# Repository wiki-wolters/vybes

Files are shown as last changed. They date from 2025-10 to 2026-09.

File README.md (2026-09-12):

# Vybes, a home DSP project

Vybes is a DSP, designed for flexibility and multiple presets covering parametric EQ, FIR
filter room correction, speaker delays, and subwoofer crossover, all controlled via a web
interface over WIFI.

## Internals

At the core of the device is a Teensy 4.1 with a 600MHz processor. The Teensy is
responsible for all the digital audio manipulation: input mixing, parametric EQ, FIR
filtering, speaker delays, subwoofer crossover, and tone/pink-noise generation.

An ESP32 development board (classic DevKitC/WROOM-32 or ESP32-S3 DevKitC-1 - both are supported build targets) is responsible for connecting to WIFI, serving the
web UI and API, and managing Teensy state. Preset configuration is stored on the
ESP32's flash (LittleFS, as MessagePack), alongside the built web UI assets.

Audio inputs (into the Teensy):
* SPDIF Toslink optical
* Bluetooth receiver via I2S
* USB audio (the Teensy enumerates as a USB sound card; built with `USB_MIDI_AUDIO_SERIAL`)
* Analogue stereo line-in via a second I2S input (an ADC board)

Audio outputs:
* Analog L & R via an I2S DAC board (PCM5102A)
* Analog subwoofer via a second PCM5102A I2S DAC board
* SPDIF pass-through out

Other hardware handled by the ESP32:
* A 1602 backlit LCD (via an I2C PCF8574 backpack) shows the current preset name. The
  backlight turns on when the preset changes and turns off after a few seconds.
* A front button: a short press wakes the LCD backlight, further presses cycle through
  presets (the selection is applied one second after the last press). Holding the button
  for ~3 seconds triggers Bluetooth pairing (the ESP drives the Bluetooth module's
  pairing line high while held).
* An IR receiver, so a spare remote control can drive volume up/down, mute, and
  next/previous preset.

WIFI credentials are provisioned by WiFiManager: if the ESP32 can't connect, it
automatically opens a "Vybes-Config" access point that a phone can join to enter
credentials. Once on the network it registers itself via mDNS so the device is
reachable at http://vybes.local.

The server also listens on **https://vybes.local** when TLS certificates are
present on the device (LittleFS `/certs/server.crt` + `/certs/server.key`;
without them it serves plain HTTP only). Generate them with `ESP/make-certs.sh`
(uses [mkcert](https://github.com/FiloSottile/mkcert)) and flash with
`pio run -d ESP -t uploadfs`. Trust the mkcert root CA on a phone or laptop
(instructions in the script header) and the browser treats the device as a
secure origin — which is what allows microphone access for the Analyzer's mic
overlay, notably on iOS where there is no insecure-origin override.

The config portal also has a "Standalone mode (no router)" button for use away from
any WIFI network (e.g. in the car): it brings up a plain "Vybes" access point
(password `vybes-dsp`) serving the full web UI at http://192.168.4.1. The AP
deliberately has no captive portal or internet, so phones keep streaming (Spotify,
Bluetooth audio) over cellular while connected to it — confirm the "no internet,
stay connected?" prompt once. Standalone mode lasts until the next power cycle.

FIR filter files live on an SD card in the Teensy 4.1's built-in slot; the ESP asks the
Teensy for the list of available files and tells it which file to load per channel.

## Presets

Up to 8 presets are stored (see `ESP/esp-web-server/config.h`). Presets follow the
8-output channel architecture (see `docs/CHANNEL_ARCHITECTURE.md`): a routing matrix
into eight identical output channels rather than a fixed left/right/sub set. Each
preset contains:

* Name (max 15 characters) and a speaker-setup template reference
* Input EQ (the shared "preference curve"): up to 15 points (frequency, gain, Q)
  plus an enabled flag, and a *dynamic EQ* that follows the volume — a reference
  anchor, an optional louder one sharing the same bands, and an automatic
  ISO 226-derived loudness compensation below the reference. See
  [docs/DYNAMIC_EQ.md](docs/DYNAMIC_EQ.md).
* Crossover points: named frequency + enabled pairs that outputs reference for
  their high- and low-pass filters (a shared point keeps linked outputs in sync)
* Eight outputs, each with: label, enable, source mix (per-bus gains), high-pass
  and low-pass crossover assignment, gain, delay in microseconds, FIR filter
  filename, a per-output PEQ (up to 10 points) + enabled flag, mute, and invert
* Preset-level enable flags for delays and FIR filtering
* Master volume (0-100): each preset remembers the level it was last played at,
  and activating a preset restores it

Global (non-preset) state includes dim (volume-reduction) state and percentage,
input gains (bluetooth, spdif, usb, analog, plus the tone/noise and SD-playback
levels), and the tone/pink-noise generator settings.

## Web UI

A Vue 3 + Vite single-page app (in `/WebUI`), served by the ESP32. Three views, plus
a persistent generator dock (tone / pink noise with a start/stop button — frequency
for the tone, and a level per source) available from every view:

### Home
* Presets: a button for each, and a plus icon to add new. Tapping the active preset's
  edit icon navigates to the preset editor. Switching is locked while recording.
* Master volume slider (the active preset's stored level)
* Speaker on/off toggles
* Dim: volume-reduction percentage slider and on/off toggle
* Input source: a stereo peak meter on the summed input bus (all sources plus SD
  playback — the point that clips when sources stack up, and exactly what the
  recorder captures), and gain sliders in dB for Bluetooth, TV (SPDIF), USB, and
  Analog
* Dynamics: the multiband compressor controls
* Recorder: record the input mix or playback to the Teensy's SD card, and play
  recordings back
* Configuration: backup and restore buttons (download/upload the full device config;
  restore is locked while recording)

### Analyzer
Real-time 31-band (1/3-octave) spectrum overlay:
* Source trace: the Teensy taps the L+R input mix (pre-DSP) with an FFT and
  streams band levels while the page is open
* Microphone trace: captured in the browser via Web Audio, aggregated into the
  same bands. Mic calibration is applied from a built-in profile (a generic
  smartphone high-pass model, or an iPhone 17 Pro curve digitised from Faber
  Acoustical's anechoic measurement) or an imported REW-style cal file
  (.txt/.cal/.frd/.csv); the choice persists in the browser.
* The capture is requested raw (no echo cancellation, noise suppression, or auto
  gain) and what the browser actually granted is read back and displayed —
  including an explicit "unknown" when the browser won't say
* The mic trace is auto level-aligned to the source (median offset over the
  analysis band), and a delta chart shows mic − source: where the room and system
  boost or lose energy. Play pink noise for the most meaningful delta.
* Exponential averaging (0.5–8 s) smooths both traces and absorbs the timing
  difference between the device tap and the mic path
* Auto-EQ ("EQ Correction"): capture the delta at one or more mic positions
  (power-domain averaged), pick a target curve (flat, tilt, Harman, B&K, or a
  custom REW import), set correction strength and boost/cut limits, preview the
  fitted bands, and apply — either to the shared input EQ, or to a single output
  (the device solos that output while measuring, and the fit is confined to its
  crossover passband)
* Note: browsers only expose the microphone on secure origins (HTTPS or
  localhost), so the mic overlay doesn't work on a phone browsing the device
  over plain HTTP. On a laptop, Chrome's
  `#unsafely-treat-insecure-origin-as-secure` flag is the workaround.

### Preset editor
Rename, copy, and delete buttons and a speaker-setup template badge, then two tabs:

**Tuning** — the day-to-day controls:
* EQ: the shared input EQ — an interactive parametric chart with draggable points
  and a calculated frequency-response curve, plus REW import (paste REW's "Export
  filter settings as text" output or choose the exported .txt; peaking (PK)
  filters are imported, up to the band limit). Above the chart are the dynamic-EQ
  controls: the reference volume the curve is tuned at, an optional loud anchor
  (add / move to the current volume / remove) with a Reference | Loud switch for
  which set of gains the chart edits, and the loudness-compensation toggle. A
  dashed "Now at NN%" curve shows what is actually playing when it differs from
  the curve being edited. See [docs/DYNAMIC_EQ.md](docs/DYNAMIC_EQ.md)
* FIR filters: a file dropdown per enabled output listing the filter files on the
  device's SD card (a configured-but-missing file stays selectable rather than
  being silently blanked, and there's a free-text fallback when the list is
  unavailable), with a taps-used counter against the device's FIR pool
* Crossovers: the preset's named crossover points (frequency + enable), each
  showing which outputs' high-/low-pass filters reference it
* Speaker delays: an input per enabled output, in microseconds, plus an
  "Auto-align with phone mic" wizard on the active preset — it plays chirps
  through each output and measures arrival times with the phone's microphone
* Output levels: a gain slider per enabled output
* Master volume: the level this preset plays at, restored whenever it is activated

**Channels** — the full 8-output matrix, one strip per output: editable label,
enable toggle, source mix, high-pass and low-pass crossover assignment (with a
protected floor when one is set), gain, delay, FIR file, a per-output PEQ (up to
10 bands, same editor and REW import as the input EQ), and mute/invert toggles.
A FIR pool bar tracks tap usage and load errors across outputs.

## API

HTTP on port 80 and HTTPS on 443 (same routes; HTTPS only when certificates are installed). Parameters are query strings unless a JSON body is noted.

### System
* **GET /status** — current state: speaker gains, input gains, mute, tone and noise
  generator settings, master volume, and the active preset name
* **PUT /volume?value={0-100}[&preset_name={name}]** — master volume. It is stored
  per preset: without `preset_name` the write lands on the active preset (the live
  master volume); naming a preset sets the level it will play at without changing
  what is playing now
* **PUT /mute?state={on|off}**
* **PUT /mute/percent?percent={0-100}** — how much mute reduces the volume
* **GET /backup** — download the device configuration (MessagePack)
* **POST /restore** — upload a previously downloaded configuration (multipart file)

### Gains
* **PUT /gains/speaker?speaker={left|right|sub}&value={0-100}** — gain in percent
* **PUT /gains/input** — JSON body, any of: `{ "spdif": n, "bluetooth": n, "usb": n, "tone": n, "analog": n }`
* **GET /preset/gains?preset_name={name}**
* **PUT /preset/gains?preset_name={name}** — JSON body of per-speaker gains

### Signal generator
* **PUT /generate/tone?frequency={20-20000}&volume={0-100}**
* **PUT /generate/tone/stop**
* **PUT /noise?level={0-100}** — 0 turns noise off

### Preset management
* **GET /presets** — all presets with names and which is current
* **GET /preset?name={name}** — full preset configuration
* **POST /preset?action=create&name={name}**
* **POST /preset?action=copy&source={name}&destination={name}**
* **PUT /preset?action=rename&old_name={name}&new_name={name}**
* **DELETE /preset?name={name}**
* **PUT /preset/active?name={name}** — switch the active preset

### Preset configuration
* **PUT /preset/delay?preset_name={name}&speaker={left|right|sub}&value={0-20000}** — delay in µs (20 ms max)
* **PUT /preset/delay/enabled?preset_name={name}&state={on|off}**
* **PUT /preset/eq?preset_name={name}** — JSON body: array of `{ "freq": 20-20000, "gain": -15-15, "q": 0.1-10 }`
* **PUT /preset/eq/point?preset_name={name}** — JSON body: single point `{ "id": 0-14, "freq": n, "gain": n, "q": n }`
* **PUT /preset/eq/enabled?preset_name={name}&enabled={on|off}**
* **PUT /preset/crossover?preset_name={name}&frequency={20-20000}**
* **PUT /preset/crossover/enabled?preset_name={name}&enabled={on|off}**

### FIR filters
* **GET /fir/files** — list of filter files on the Teensy's SD card
* **PUT /preset/fir?preset_name={name}&speaker={left|right|sub}&file={filename}**
* **PUT /preset/fir/enabled?preset_name={name}&state={on|off}**

### Live updates (WebSocket)
* **ws://vybes.local/live-updates** (or `wss://` when the page is served over HTTPS)
  * State changes are broadcast to all connected clients as JSON with a `messageType`
    field: `volumeChanged` (with the `presetName` the level belongs to),
    `muteChanged`, `mutePercentChanged`, `activePresetChanged` (which carries the
    newly active preset's `volume`),
    `delayChanged`, `delayEnabledChanged`, `eqPointsChanged`, `eqEnabledChanged`,
    `crossoverChanged`, `crossoverEnabledChanged`, `firChanged`, `firEnabledChanged`,
    plus payload fields (usually `presetName` and the new value).
  * Tone and noise updates are broadcast as `{ "toneFrequency": n, "toneVolume": n }`
    and `{ "noiseVolume": n }` (no `messageType` field).
  * RTA: clients send the text message `rta:keepalive` every 2 s while they want
    spectrum data; the server relays the interest to the Teensy and broadcasts
    frames as `{ "type": "rta", "d": "<62 hex chars>" }` — two hex digits per
    band (31 bands, 20 Hz–20 kHz), value = (dB + 100) × 2. Streaming stops a few
    seconds after the keepalives do.

## Directories
* `/ESP`: ESP32 web server firmware (API, WebSocket, HTTPS, LCD, button, IR remote, WIFI)
* `/Teensy`: Teensy DSP firmware (`fir_filters/`)
* `/WebUI`: Vue 3 web UI
* `/mock-server`: Express + SQLite mock of the device API, for developing the web UI
  without hardware (includes the WebSocket endpoint)
* `/docs`: wiring and protocol documentation
* `/3d`: 3D-printable case models

## Building and flashing

Both firmwares build with [PlatformIO](https://platformio.org) — no Arduino IDE needed.
PlatformIO downloads the right toolchains, frameworks, and libraries automatically on
the first build.

### One-time setup

Install the PlatformIO CLI, e.g. one of:

```sh
brew install platformio    # macOS (Homebrew)
pipx install platformio    # anywhere with Python
pip install platformio     # what CI uses
```

(Alternatively, install the "PlatformIO IDE" extension in VS Code, which bundles the
`pio` CLI and adds build/upload buttons.)

The web UI needs Node.js. Install its dependencies once:

```sh
cd WebUI && npm install
```

### Teensy (DSP firmware)

```sh
pio run -d Teensy             # compile only
pio run -d Teensy -t upload   # compile and flash over USB
```

Upload uses the Teensy loader bundled with the PlatformIO Teensy platform. If the
upload sits waiting for the board, press the program button on the Teensy.

### ESP32 (web server firmware + web UI)

The ESP32's flash holds two separate images, uploaded by two separate commands:
the firmware (the compiled C++ program) and a LittleFS filesystem image (the built
web UI assets, TLS certificates, plus presets saved at runtime).

1. Flash the firmware:

   ```sh
   pio run -d ESP -t upload            # classic ESP32 (add -e esp32s3 for the S3)
   ```

2. (Optional, for HTTPS) generate TLS certificates into the filesystem staging
   directory - only needed once, and only if you want the mic-capable secure
   origin:

   ```sh
   ./ESP/make-certs.sh
   ```

3. Build the web UI - the ESP's filesystem staging directory
   (`ESP/esp-web-server/data/dist`) is a symlink to `WebUI/dist`, so the
   build lands there directly:

   ```sh
   cd WebUI && npm run build && cd ..
   ```

4. Pack `ESP/esp-web-server/data` into a LittleFS image and flash it:

   ```sh
   pio run -d ESP -t uploadfs          # add -e esp32s3 for the S3
   ```

Note: `uploadfs` replaces the *entire* filesystem, including presets saved on the
device. To keep them, download **GET /backup** before flashing and **POST /restore**
afterwards.

Both upload targets auto-detect the USB serial port. If more than one device is
plugged in, find the right port with `pio device list` and pass
`--upload-port <port>`.

To watch ESP debug output: `pio device monitor -b 115200` (the ESP's debug UART is on
D4/GPIO2 — see [docs/WIRING.md](docs/WIRING.md) for the pinout).

GitHub Actions compiles all three on every push (`.github/workflows/build.yml`).

## ESP ↔ Teensy link

The two boards communicate over UART (115200 baud) using a newline-delimited text
protocol. On boot the Teensy sends `EVENT boot` and the ESP pushes the full DSP state,
so either device can restart independently and the system converges. See
[docs/WIRING.md](docs/WIRING.md) for the wiring, the serial protocol, and the
debug-console pinout.

## License

Vybes is free software, released under the [GNU General Public License v3.0](LICENSE)
(or any later version). You may use, modify, and distribute it under the terms of that
license; if you distribute modified versions, the source for your changes must be made
available under the same license.

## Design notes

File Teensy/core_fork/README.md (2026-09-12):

# Vybes Teensy core fork

Forked files from the `framework-arduinoteensy` package (Teensyduino core),
installed into `~/.platformio/packages/framework-arduinoteensy/cores/teensy4/`
by `../core_fork_sync.py`, which runs automatically before every `teensy41`
build (`extra_scripts` in `platformio.ini`). No manual step: a fresh checkout
patches the package on first build. The pristine file is kept next to the
patched one as `<name>.vybes-orig`.

## Why

The stock USB audio input (`AudioInputUSB`) buffers at most 2 audio blocks
(~5.8ms) between the USB interrupt and the audio update, targeting a
64-sample occupancy. Host packet delivery is bursty at millisecond scale, so
the buffer regularly overflowed (dropped samples) and drained (inserted
silence) - audible as occasional clicks during USB playback, regardless of
CPU load or sample-rate matching. Measured on hardware 2026-08-09: ~10
overruns + ~1 underrun per 20s window while streaming at 5% CPU.

## Changes in `usb_audio.cpp` (all marked `VYBES`)

1. **`usb_audio_rx_hook(const int16_t *lr, unsigned int frames)`** - weak
   `extern "C"` hook offered every incoming isochronous packet before any
   buffering. Return nonzero to consume the packet. `AsyncAudioInputUSB`
   (in `fir_filters/`) defines the strong version and owns rate matching via
   resampling; the feedback endpoint then keeps reporting nominal 44.1kHz.
2. **Deep receive queue** - 8-block ring targeting 1 block of occupancy
   (~4.4ms input latency, ~20.3ms burst absorption) instead of the stock
   2-block / 64-sample scheme. Queue depth is exported as
   `volatile uint8_t usb_audio_rx_queue_count` for monitoring. The target and
   the depth are independent knobs: the target alone sets latency, the depth
   alone sets how big a host burst is absorbed. It ran at a target of 3
   (~10.2ms) while `AsyncAudioInputUSB` was the default input; 1 keeps more
   burst headroom than stock while costing ~1.5ms over it.
3. **Damped feedback loop** - the stock proportional-only correction acts on
   a double-integrator plant (occupancy integrates rate error, the
   accumulator integrates the correction), i.e. an undamped oscillator that
   never settles. A derivative term (`err + 16*(err - prev_err)`) makes it
   near critically damped; the crude `+3500` underrun kick is removed.

## Updating the platform package

When the Teensy platform/package updates, `core_fork_sync.py` aborts the
build with a hash mismatch. Re-merge: diff `usb_audio.cpp` here against the
new core file (the `VYBES` markers delimit every change), port the changes,
then refresh the hash:

```bash
shasum ~/.platformio/packages/framework-arduinoteensy/cores/teensy4/usb_audio.cpp | cut -d' ' -f1 > Teensy/core_fork/usb_audio.cpp.upstream.sha1
```

(run before the sync script has patched the new package - i.e. right after
the package update, or against the `.vybes-orig` backup).

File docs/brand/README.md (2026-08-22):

# Vybes brand assets

The wordmark's V is a true inverted Gaussian — a parametric-EQ bell cut
with its control dot floating in a negative-space halo — plus "ybes" set in
Poppins (OFL licence), converted to outlines: Medium in the display cut
(114-unit stems matched to the 110-unit curve), SemiBold in the small cut
(matched to its 145-unit curve). The lockup gap is -15 units — the bell's
tail nests over the "y". No font is needed to use any of these files. All SVGs are filled outlines (no strokes,
no text elements), so they import cleanly into CAD, cutters, and print RIPs.

## Colour

| Token | Hex | Use |
|---|---|---|
| Teal 500 | `#17808D` | Primary. Light backgrounds, and interactive FILLS in the UI (white text on it is 4.7:1). As text on dark it is only 3.7:1 — fails AA. |
| Teal 300 | `#45AEBC` | Wordmark/mark, active-state text and thin chart lines on dark UI (6.6:1 on `#161b22`). |
| Teal 600 | `#136B77` | Hover state for Teal 500 fills. |
| Teal 700 | `#0F5761` | Duotone accents. |

CMYK for Teal 500 ≈ C84 M9 Y0 K45 (naive conversion — proof against the
printer's profile before volume runs). Prefer the black mono files for
single-colour print.

## Files

**Screen**
- `vybes-wordmark.svg` — primary (Teal 500, light grounds), ≥ 32 px tall.
- `vybes-wordmark-small.svg` — small-size cut for 16–32 px tall (heavier
  curve; the halo is scaled up with the stroke so it stays open at these
  sizes). Below 16 px use the mark alone.
- `vybes-wordmark-reversed.svg` / `-teal-light.svg` / `-black.svg` — white,
  dark-UI teal, and mono colourways of the primary cut.
- `vybes-mark.svg` (+ `-white`, `-black`) — standalone icon-cut mark.
- `vybes-favicon.svg` — 64 px tile, dark ground + Teal 300. The one solid-dot
  file: below ~20 px the halo dies, so the favicon keeps the dot filled.
- `vybes-app-icon.svg` — 512 rounded tile (purpose `any`).
- `vybes-app-icon-maskable.svg` — full-bleed, mark inside the 80% safe
  circle (purpose `maskable`). Keep these two as separate manifest entries.
- `vybes-app-icon-dark.svg` — dark-tile alternative.

**Print**
- Use `vybes-wordmark.svg` (coated stock) or `-black.svg` (single colour).
- Minimum height: 8 mm primary cut, 5 mm small cut.
- Clear space all round: the dot diameter (≈ 28% of wordmark height).

**3D printing / CNC / laser**
- `vybes-3d-wordmark-solid.svg` — sized 80 mm wide in the file; thinnest
  feature 2.0 mm and a 1.5 mm halo moat at that size (safe for a 0.4 mm
  nozzle down to ~34 mm wide).
- `vybes-3d-mark-solid.svg` — sized 30 mm; thinnest feature 3.5 mm.
- `vybes-3d-wordmark-stencil.svg` — counters of b/e bridged (the halo dot
  needs no bridge — material connects through the halo openings); use for
  cut-through stencils or deep deboss moulds where islands would fall out.
  Thinnest feature 1.4 mm at 80 mm wide (min width ~46 mm on FDM).
- `vybes-badge.stl` — ready to print: 90×34×2 mm plate, logo raised 1.2 mm.
- `vybes-coin.stl` — ⌀30 mm coin, mark raised 1 mm.
- Emboss (raised) and engrave (recessed) can use the solid files as-is;
  only cut-through work needs the stencil file.

## Regenerating

`tools/` holds the geometry generators (`pip install shapely fonttools
trimesh mapbox_earcut numpy`, then `python gen_final.py` for the SVGs and
`python gen_stl.py` for the STLs, run from `tools/`). The V is generated,
not drawn: `y(x) = tail_y − depth·e^−((x−c)²/2σ²)` — tune `sigma` in
`gen_final.py` to widen or tighten the bell. Poppins Medium and SemiBold TTFs are
included (OFL) so the letterforms regenerate identically.

## Study references (not production assets)

`vybes-wordmark-semibold/-medium/-regular.svg`, `vybes-dot-*.svg` and
`vybes-gap-*.svg` are frozen exploration files backing the study boards on
the design canvas. Don't ship them.

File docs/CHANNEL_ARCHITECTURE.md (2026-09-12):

# 8-Output Channel Architecture (Config V1)

Design agreed 2026-07-25. This replaces the fixed left/right/sub model with a
MiniDSP-Flex-style routing matrix and eight identical output channels, matching
the octal I2S output hardware. This is a clean break: new Teensy + ESP32-S3
hardware, no migration from the old 3-channel config. The new schema starts at
**version 1**, but the version field and a migration hook are kept from day one
so future schema changes can migrate in place.

Deferred (discussed, not in scope for V1):

- Multirate sub FIR (decimate /8, FIR at ~5.5kHz, interpolate back). Saves ~8x
  taps and ~64x CPU on sub channels; revisit when the tap pool gets tight.

## Signal flow

```
inputs (spdif/bt/usb/analog/gen)
  -> input mixers (existing)
  -> input EQ (shared L/R preference curve — room/house correction, and the
     volume-following dynamic EQ of docs/DYNAMIC_EQ.md)
  -> routing matrix (per-output source gains for L and R buses)
  -> 8x output channel: HP + LP crossover -> output PEQ -> FIR -> delay
     -> gain / invert / mute
  -> octal I2S (and SPDIF mirrors outputs 0/1)
```

The Teensy stays dumb and per-channel: it knows nothing about crossover
objects, templates, or linking. All linking/reference resolution happens on the
ESP; the Teensy receives only resolved per-channel values.

## Config schema (V1)

As implemented: the mock server (mock-server/server.js + templates.js) and the
contract suite (WebUI/tests/contract/api-contract.test.js) are the executable
spec for the ESP32-S3 firmware.

```jsonc
{
  "version": 1,
  "active_preset_index": 0,
  "presets": [
    {
      "name": "Default",
      "template": "2.1",              // template id, or "custom" once edited beyond it
      "crossovers": [                  // shared crossover points (max 4)
        { "id": "sub_xo", "freq": 80, "type": "LR4", "locked": false, "min": 40, "max": 500 }
      ],
      "inputEq": {                     // see docs/DYNAMIC_EQ.md
        "enabled": true,
        // spl is a ROLE tag, not an SPL: 0 reference anchor, 1 loud anchor.
        // Both sets share band count, frequencies and Qs; only gains differ.
        "sets": [ { "spl": 0, "points": [ { "freq": 1000, "gain": 0, "q": 1 } ] } ],
        "referenceVolume": 50,         // slider percent the curve is tuned at
        "loudVolume": 0,               // slider percent; 0 = no loud anchor
        "loudness": true               // ISO 226 compensation below reference
      },
      "outputs": [                     // always 8 entries
        {
          "label": "Left",             // user-editable, shown everywhere in the UI
          "enabled": true,             // unused channels render collapsed/grey
          "source": { "left": 1.0, "right": 0.0 },   // mono sub = 0.5 / 0.5
          "hp": { "mode": "xover", "xover": "sub_xo" }, // mode: off | xover | manual
          "lp": { "mode": "off" },     // manual mode carries freq + type (LR2|LR4|BW2);
                                       // "off" keeps a previous xover ref for re-enable
          "hpFloor": 0,                // safety floor in Hz, see Safety model
          "peq": [ { "freq": 1000, "gain": 0, "q": 1 } ],  // max 10 per output
          "fir": "",                   // filename; '' = none. Enable is preset-level
          "delayUs": 0,                // capped at 20000 (existing decision)
          "gainDb": 0.0,               // -40..+10 dB
          "invert": false,
          "mute": false
        }
      ],
      "delaysEnabled": false,          // preset-level master toggles (A/B comparison)
      "firEnabled": false,
      "volume": 50                     // master volume 0-100, restored on activation
    }
  ]
  // global system state (mute, input gains, tone/noise) unchanged
}
```

Template ids: `2.0`, `2.1` (default), `2.2`, `2way-sub`, `3way`, `3way-2sub`.
Structural edits (source mix, HP/LP sections, enabling outputs) flip
`template` to `"custom"`; tuning edits (gain, delay, PEQ, FIR, mute, labels)
keep it. GET /preset additionally reports `firPool: {used, total}`.

### Limits

| Constant | Value | Why |
|---|---|---|
| `NUM_OUTPUTS` | 8 | octal I2S |
| `MAX_CROSSOVER_POINTS` | 4 | 3-way + sub needs 3; one spare |
| `MAX_OUTPUT_PEQ` | 10 | per output; MiniDSP-class. 8x10 SVF bands ~= 8% CPU, no global pool needed |
| `MAX_INPUT_PEQ` | 15 | unchanged, per SPL set (`MAX_PEQ_SETS` = 3) |
| `FIR_TAP_POOL` | 12288 | shared across all outputs, allocated at load; UI shows used/total |
| `MAX_DELAY_US` | 20000 | per channel, existing AudioMemory constraint (re-verify pool size at 8 delays) |

## Crossover points and the safety model

Crossover points are first-class named objects. A channel's HP/LP either
references one (`"mode": "xover"`) or owns a literal value (`"mode":
"manual"`). Editing a crossover point updates every filter that references it
in one operation — this is what makes the "sub crossover" slider adjust the
sub's LP and the mains' HP together. No general-purpose variable/macro system;
shared crossover points plus channel link groups (later) cover the real cases.

**Locked crossovers.** A mis-drag on a mid or tweeter crossover while music is
playing can fry a driver, so crossover points carry a `locked` flag:

- `locked: false` (e.g. `sub_xo`): rendered as a slider, live-editable within
  its template-defined range. Same UX as today.
- `locked: true` (e.g. `mid_xo`, `twt_xo`): rendered **view-only**. Editing
  requires an explicit flow: Edit button -> type new value -> Save -> Confirm.
  These values are set once during system setup and rarely touched.

Enforcement is server-side, not just UI: the ESP rejects a change to a locked
crossover unless the request carries `confirm=true`, and there is no
websocket/live-drag path for locked points. The UI merely reflects the rule.

**HP floor.** Each output has an `hpFloor` (Hz, 0 = none). The ESP rejects any
change that would leave the channel's effective high-pass below the floor —
whether by editing a crossover point, switching HP to manual, or turning HP
off. Templates set floors for fragile drivers (e.g. tweeter channels get
`hpFloor` well below the expected crossover but far above DC). This also closes
the classic bypass hazard: a global "crossover enabled" toggle must not exist
in a multi-way system; bypass is per-section and floor-checked.

## Templates

A template is a **factory, not a mode**: applying one generates the outputs
array, labels, crossover points (with locked flags and slider ranges), source
mixes, and hpFloors. Everything remains editable afterward in the advanced
view. The preset records its template id so the UI knows which simple view to
render; edits the simple view can't express flip it to `"custom"`.

| Template | Outputs | Crossover points (locked?) |
|---|---|---|
| 2.0 Stereo | L, R | — |
| 2.1 (default) | L, R, Sub | sub_xo (slider) |
| 2.2 | L, R, Sub 1, Sub 2 | sub_xo (slider) |
| 2-way active + sub | L/R woofer, L/R tweeter, Sub | sub_xo (slider), twt_xo (locked) |
| 3-way active | L/R low, L/R mid, L/R high | mid_xo (locked), twt_xo (locked) |
| 3-way + 2 subs | all 8 | sub_xo (slider), mid_xo (locked), twt_xo (locked) |

The 2.1 template reproduces today's product exactly (home view: volume, sub
level, sub crossover slider), so the simple experience is unchanged by default.

## Serial protocol (channel-indexed)

Positional 3-channel commands are replaced with output-indexed ones. The ESP
resolves crossover references before sending; the Teensy only ever sees
per-channel numbers.

```
setOutputGain   <ch> <db>
setOutputMute   <ch> <0|1>
setOutputInvert <ch> <0|1>
setOutputSource <ch> <lGain> <rGain>
setOutputDelay  <ch> <us>
setOutputHp     <ch> <freq> <type>     # freq 0 = off (subject to hpFloor on ESP side)
setOutputLp     <ch> <freq> <type>
setOutputEq     <ch> <band> <freq> <q> <gain>
setFir          <ch> <file>            # bare "setFir <ch>" clears
setFirEnabled   <ch> <0|1>
setInputEq      <band> <freq> <q> <gain>   # shared input EQ, unchanged semantics
setInputEqLoudGain <band> <gain>       # dynamic EQ: loud-anchor gain (docs/DYNAMIC_EQ.md)
setInputEqAnchors  <refPct> <loudPct>  # 0-100; loud 0 = no loud anchor
setLoudness        <0|1>               # loudness compensation below reference
```

`teensy_protocol.h` stays pure C so the host-native round-trip tests keep
covering every command.

## Teensy firmware changes

- Named per-channel objects and patchcords collapse into arrays sized
  `NUM_OUTPUTS`, built in a loop: source mixer, biquad HP/LP cascade, PEQ, FIR,
  delay, output amp per channel.
- The fixed `AudioFilterStateVariable` crossover pairs are replaced by a
  per-channel biquad cascade (up to LR4 HP + LR4 LP = 4 biquads).
- Bypass moves inside each processing object (PEQ already has `setBypass`);
  the connect/disconnect patchcord-swapping arrays do not scale to 8 channels.
- FIR: `MAX_FIR_TAPS` per-channel cap becomes a shared pool (`FIR_TAP_POOL`
  taps, ~16 bytes/tap with fast convolution). Loads that exceed the remaining
  pool are rejected with a clear error the UI can surface.
- Benchmark 8 concurrent fast-convolution engines before trusting the pool
  number — current 3-channel builds are RAM-limited, but 8x FFT work is new.

## Web UI plan

Two-layer model: the **simple view** is template-driven and stays the default
experience (2.1 looks exactly like today); the **Channels view** is the
Flex-style advanced editor. Both edit the same preset — the simple view is a
projection of it, not a separate mode.

### Views

- **HomeView** (daily driver) — unchanged in role: presets, master volume,
  input sources, mute. The hardcoded Left/Right/Sub speaker toggles become
  template-derived mute groups (e.g. "Subs" toggles all sub-labeled outputs).
  Master volume is stored on the preset, so the slider here writes the active
  one and follows preset switches.
- **PresetEditorView** becomes tabbed: **Tuning** | **Channels**.
  - *Tuning* (simple view, per template): input EQ (EQSection: the curve plus
    its dynamic-EQ anchors), Crossovers card, speaker-group levels and delays, FIR per
    output. For the 2.1 template this is today's editor, nearly unchanged.
  - *Channels* (advanced): eight channel strips — editable label, source mix,
    HP/LP summary, output PEQ (opens ParametricEQ), FIR file select, delay,
    gain, invert, mute. Desktop: strip columns; mobile: stacked accordion
    cards (iPhone is a first-class target). Editing anything the template's
    simple view can't express flips the preset to "custom" (with a notice).

### Crossovers card and the locked-edit flow

One card lists the preset's crossover points:

- Unlocked (`sub_xo`): existing RangeSlider, live, within template range.
- Locked (`mid_xo`, `twt_xo`): read-only value + lock icon + Edit button.
  Edit opens a ModalDialog: numeric input -> Save -> confirmation step that
  shows old value, new value, and the list of affected channel filters
  ("HP on L Mid, R Mid; LP on L Low, R Low") -> Confirm sends the request
  with `confirm=true`. No slider is ever rendered for a locked point.
- ESP-side rejections (locked without confirm, hpFloor violations, FIR pool
  exhaustion) surface as inline errors on the control that caused them.

### New components

`ChannelStrip.vue`, `SourceMixInput.vue`, `CrossoverCard.vue`,
`LockedValueModal.vue`, `FirPoolBar.vue` (used/total taps, shown wherever FIR
files are picked), `TemplateSelect.vue` (in the new-preset modal). Everything
else reuses the existing kit; the FIR file dropdown keeps the current
missing-file and no-SD fallbacks from PresetEditorView.

### State

Introduce a single preset-config store (Pinia or a shared composable): with 8
channels, shared crossover points, and a global tap pool, cross-cutting state
no longer fits the current per-view fetch pattern. Websocket messages mutate
the store; views render from it. Keep the existing debounced-PUT pattern for
sliders.

### Build order

1. Mock server + api-client updated to the V1 schema (UI work proceeds
   without hardware).
2. Config store + PresetEditorView restructured to tabs; Tuning tab reaches
   parity with today's editor via the 2.1 template.
3. Crossovers card with the locked-edit flow.
4. Channels tab (strips, source mix, per-channel PEQ, FIR + pool bar).
5. Template picker on preset creation; custom-flip logic; HomeView mute
   groups.
6. Later: stereo link groups, crossover/PEQ response overlay on the RTA.

## Auto delay alignment (phone-mic probe)

Per-output delays can be measured instead of guessed. The Teensy plays one
log chirp per enabled output at exact sample offsets on its own audio clock;
the phone records the whole sequence in one take and the web UI
cross-correlates to recover each chirp's arrival. Because a single
continuous recording is analyzed, network, Bluetooth and start-time latency
are common to every chirp and cancel — only the deviations from the known
spacing survive, and those are the relative acoustic flight times.

**Chirp contract** (the `PROBE_*` constants in `teensy_protocol.h`, mirrored
in `mock-server/templates.js` and echoed in the API response so the UI never
hardcodes them): 44.1kHz, 60Hz–8kHz log sweep, 16384-sample chirp with
512-sample raised-cosine fades, 49152-sample spacing, 65536-sample pre-roll,
8192-sample tail. Chirp *k* starts at `preRoll + k * spacing`. The spacing
leaves a ~743ms gap so the output amps' 60ms-tau solo ramp (~342ms to
settle) finishes well before the next chirp.

**Order** is the enabled outputs ascending, then the same list reversed.
Averaging each output's two arrivals cancels linear phone-clock drift, since
slot *k* and slot *2N−1−k* always straddle the same midpoint in time.

**Protocol.** `startDelayProbe <mask> <level>` / `stopDelayProbe`; the Teensy
replies with `PROBE START|CHIRP|WARN|DONE|STOP|ERR` lines, which the ESP
relays to the websocket as `{"messageType":"probeEvent","line":"..."}`. The
sequencer has to live on the Teensy: the ESP's command queue coalesces
same-channel `setOutput*` messages and drains at loop rate, so driving the
solo sequence from there would silently drop steps.

**Level and routing.** During a probe the soloed output's amp gets a fixed
probe gain (invert honored, mute/gainDb/master volume ignored — any of them
could be zero and silence the measurement), every other output is silenced,
and the external inputs plus the tone/noise generators are muted so nothing
contaminates the recording. All of it is restored from `state` when the
probe ends, through the normal ramp, so start and end are click-free.

**Delay semantics.** The probe runs with the user delays *active* and the
full chain (crossover, PEQ, FIR) in place, so it measures real acoustic
arrivals. Corrections are therefore incremental: align to the latest
arrival, re-normalize so the smallest delay is 0, clamp at `MAX_DELAY_US`.
Re-running converges. FIR group-delay compensation is identical-latency
padding across outputs, so it contributes nothing to the relative offsets
and needs no adjustment.

**Mutual exclusion is the UI's job**: no preset switches while a probe runs.
The one guard on the Teensy is a FIR load, which blocks `loop()` on SD reads
and changes channel latencies mid-measurement — that aborts the probe with
`PROBE ERR aborted firLoad`.

**Known limits.** A sub-only channel only reproduces the low end of the
sweep, so its correlation peak is broad (~±1-2ms rather than ~±0.1ms); the
UI reports per-output confidence. An output routed with both source gains at
zero can't emit the chirp at all and is reported as `PROBE WARN unrouted`.

## Versioning

`version: 1` for this schema. Keep the load-time version check and a
`migrate_config(from_version)` hook wired from the start, even though V1 has
nothing to migrate — schema changes during iteration bump the version and add
a migration step rather than silently reinterpreting fields.

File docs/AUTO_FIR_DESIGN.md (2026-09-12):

# Auto-FIR Correction (Design)

Status: **draft for discussion**, 2026-08-30. Nothing here is built. This
captures the design conversation so far; the open questions at the bottom need
decisions before implementation starts.

## Goal

Generate FIR correction filters in the browser from the device's own
measurements, replacing the manual rePhase workflow. Today the FIR path assumes
the user designs filters in external tools; the most powerful feature of the
device is gated on knowing rePhase/REW. The measurement plumbing to close that
loop already exists: chirp playback with a Teensy-side sequencer (delay probe),
per-output soloing (`soloOutput` keepalive), phone-mic capture with calibration
profiles, and a verbatim rePhase-WAV loader.

This is time-domain (phase) correction plus fine magnitude trim — the thing
MiniDSP sells as Dirac. It is *not* a replacement for the parametric auto-EQ,
which keeps a distinct job (see next section).

## Division of labor

Biquads are minimum-phase: their phase is locked to their magnitude. Only FIR
can correct **excess phase** — crossover rotation (an LR4 acoustic crossover
rotates 360°) and non-delay driver offsets — because phase *lead* relative to
minimum phase must be bought with bulk latency. That is the part of the
correction problem currently outsourced to rePhase.

Below the room's modal transition (~300–500 Hz) the argument flips: FIR
resolution is linear in frequency (4,096 taps ≈ 93 ms ≈ 12 Hz resolution —
marginal for a 35 Hz mode a single biquad notches for free), phase correction
there costs tens of ms of latency, and deep modal nulls are position-dependent
and dangerous to invert. So the layers are:

| Band | Correction | Tool | Measurement |
|---|---|---|---|
| Below transition | Room magnitude | Shared input EQ biquads (existing auto-EQ) | Multi-position pink noise (existing) |
| Above transition | Driver linearization, crossover phase, magnitude trim | Per-output FIR (this design) | Stationary-mic sweeps, time-gated |
| Sub band | Level/delay/polarity/PEQ | Existing tools; **no FIR** | Delay probe + auto-EQ (existing) |

This split is also what makes the tap pool sufficient: the expensive
low-frequency correction never gets duplicated into eight kernels.

Run order for the user: FIR wizard first, then the room auto-EQ against the
corrected speakers.

## Measurement

### Sweeps, not pink noise

The pink-noise RTA path gives a magnitude spectrum only — phone mic and Teensy
share no clock and no reference channel, so a stochastic signal can never yield
phase, and without phase there is no impulse response to design against. A
deterministic excitation with known timing does: an exponential (Farina/ESS)
sweep, deconvolved with its inverse filter. The delay probe already is most of
this — cross-correlating a known chirp *is* deconvolution; today we keep one
number from the correlation trace (the peak) and discard the rest. This design
keeps the whole deconvolved impulse response.

**Standing decision to revisit**: "no sweep-based EQ measurement" (2026-08)
was about *handheld/moving-mic* capture, where movement breaks sweep
deconvolution. This design uses a **stationary** mic — a different regime — but
the decision should be revisited explicitly, not silently overridden.

Side effect for later: ESS deconvolution separates harmonic distortion orders
into distinct pre-arrivals in the IR, so a THD-vs-frequency analyzer falls out
of the same capture nearly for free. Out of scope here.

### One position, time-gated — why reflections at the seat don't poison it

The obvious objection: reflections cause peaks at the mic position that don't
exist a few cm away. The defense is not averaging but **time-gating**. A
position-sensitive comb peak is the direct sound plus a copy arriving ms later;
in the IR they are different samples. Gate the IR to the direct arrival before
designing, and the reflections never enter the data — they arrived after the
window closed (standard quasi-anechoic technique). The gated direct field
varies only slowly with position.

The gate sets a resolution floor (~250 Hz for a 4 ms gate ahead of a typical
floor bounce) — which coincides with the transition where correction is handed
to the biquad flow anyway. Concretely:

- Frequency-dependent windowing (a constant few cycles): fine resolution up
  high, degrading gracefully downward.
- Fractional-octave smoothing on top: never invert ripple narrower than
  ~1/6 octave even in gated data.
- Excess phase is the most position-robust quantity of all — crossover phase
  rotation is a property of the drivers and filters, not the mic spot.
- Delays and polarity are the one place position-specificity is *desired*:
  time-of-flight to the actual seat.

Optional confidence step for the mid-band (200–800 Hz, where gates get long):
"add a position" — re-run the sweep sequence from a second/third **stationary**
spot, average **magnitudes only**, keep phase from the primary seat (complex
averaging across positions smears phase through differing path lengths).

### Capture hygiene

- Two sweeps per output, back to back: adaptive mic processing (AGC, noise
  suppression, Voice Isolation) shows up as inconsistency between them —
  **refuse to fit** on mismatch rather than encoding the mic's behavior into
  the correction. (Field incident: an iPhone 17 Pro auto-correction hollowed
  the vocal band; prime suspect is iOS Mic Mode / Voice Isolation, which sits
  below getUserMedia and is invisible to constraint readback. The wizard should
  tell iOS users to set Wide Spectrum.)
- Clock drift: phone ADC and Teensy DAC are on independent crystals; 50 ppm
  smears the deconvolved IR at high frequencies over a multi-second sweep.
  Estimate drift from the spacing error between the two sweeps (the sequencer
  already supports spaced chirps) and resample the capture before deconvolving.
- Mic coloration is common-mode across every capture from one position, so all
  *relative* quantities — L/R matching, crossover blending, delays, excess
  phase — are mic-agnostic. Absolute magnitude targets are the exposed part:
  correct assertively only below the transition (delegated to the biquad flow)
  and cap correction in the presence band (±3 dB in 1–5 kHz) above it.
- Existing FIRs are bypassed during measurement (the preset-level `firEnabled`
  flag) so old correction doesn't compound into new. Crossovers and PEQ stay
  active: the acoustic crossover is the thing being phase-linearized, and the
  design should compose with the EQ, not fight it.

## Filter design

### Latency budget and the two renders

The N/2 group delay belongs to linear-phase kernels specifically. A
minimum-phase kernel of the same length has essentially no inherent delay —
processing latency collapses to the first-partition size (128 samples ≈ 2.9 ms
at 44.1 kHz). The lookahead needed for phase correction scales ~1/f: under a
ms linearizes a 2.5 kHz crossover, a few ms reaches 300 Hz, tens of ms for a
sub crossover. So latency is a knob, not a binary:

- Every kernel gets the **identical bulk lead** (the chosen budget), so
  inter-output time alignment survives correction and the delay fields stay
  meaningful for trim.
- One measurement renders **twice**: a *gaming* render (0 ms budget → pure
  minimum-phase, ~3 ms latency, magnitude-only correction) and a *music* render
  (e.g. 10 ms budget → linearizes crossovers down to roughly one period of the
  budget, ~13 ms total — inside the 20 ms envelope).
- Frequency-dependent windowing in the designer confines phase correction to
  where the budget can reach; below that, minimum-phase only.

### Tap budget

The pool is 12,288 taps, charged in 128-tap partitions, shared across all
outputs. Allocation is derived from the preset topology, not hardcoded: an
output's kernel needs time-support reaching only its own passband's low edge,
so **taps ∝ 1/f_lo**, quantized to partitions. Subs get zero (see division of
labor). Worked example — 3-way stereo + 2 subs at 44.1 kHz:

| Output | Passband | Taps each | Window |
|---|---|---|---|
| Tweeters ×2 | 2.5k+ | 512 | ~11 ms |
| Mids ×2 | 300–2.5k | 1,536 | ~35 ms |
| Woofers ×2 | 80–300 | 3,584 | ~81 ms (~12 Hz resolution) |
| Subs ×2 | <80 | 0 | — |

Total 11,264 of 12,288. **Do not plan to exact-fit**: full-pool loads work but
took three crash fixes to get there; the planner defaults to leaving at least a
partition or two free. CPU note: the MAC loop dominates convolution cost and
cache stalls grow past ~16 partitions per filter, so total tap count is the
budget that matters, and it's unchanged from today's worst case.

## User workflow

0. **Plan** — wizard reads the active preset's topology (enabled outputs,
   hp/lp crossover assignments) and shows the proposed per-output tap budget
   against the FIR pool bar *before any sound plays*. The pool is the
   constraint, so it's the first screen, not an apply-time error. User can
   adjust; defaults should be right for any topology.
1. **Setup** — stationary mic at the seat (explicitly framed as different from
   the moving-mic pink-noise flow). Capture-chain readback check; Wide
   Spectrum guidance on iOS. Preset `firEnabled` **and** `inputEq.enabled`
   off for the session (input EQ is room-band correction that re-runs after
   the wizard, so it must not be baked into the driver measurement); output
   PEQ and crossovers stay active. Both flags restored afterwards.
2. **Measure** — one continuous capture session; sequencer solos each output
   in turn (existing keepalive + amp ramp), two ESS sweeps per output
   (consistency check, drift estimate, average). Shared timebase → relative
   delays between all outputs fall out for free; this replaces a separate
   delay-probe pass.
3. **Review** — per-output magnitude and excess phase with automated flags:
   polarity inversions, low-SNR captures, and outputs whose measured passband
   contradicts their hp/lp config (generalizing the 2026-08-27 sub trap).
4. **Design** — two global choices: the **house-curve target** (downward
   tilt, flat, Harman, B&K, or an imported REW-style file — the same
   selection the analyzer's auto-EQ offers, stored under one key so picking
   a curve once applies in both places; default −0.5 dB/oct) and the latency
   budget. The target is resolved onto each output's measured frequencies by
   `target-curves.js` `targetDbOnFreqs`, re-centered over that output's own
   passband, and handed to `designKernel` as `targetDb`; the predicted-result
   chart overlays it. Per-way targets shared L/R (matching between sides
   beats absolute accuracy above the transition). Render gaming + music
   kernels; show predicted latency for each.
5. **Apply** — copy the preset first (undo and A/B in one move). Write kernels
   as rePhase-compatible WAVs named per output + version, upload to SD, assign
   to outputs, write delays from the same measurement.
6. **Verify** — one short re-sweep pass, before/after overlay.

## Firmware prerequisites (gaps as of 2026-08-30)

1. **FIR file upload path** — there is none. `api_fir.cpp` has list / enable /
   pool / assign routes only. Needs chunked browser → ESP → UART → Teensy → SD
   transfer, with the ESP's heap fragility in mind (small chunks, no large
   buffered bodies).
2. **Full IR return to the browser** — the delay probe returns a delay number;
   this needs the deconvolved capture (or the raw capture for browser-side
   deconvolution — likely the better split: browser has the FFT muscle and the
   captured audio already lives there; the Teensy only needs to sequence and
   solo). Amount of new Teensy work may therefore be small.
3. **Sweep excitation** — confirm the probe chirp is (or becomes) a true
   exponential sweep with a defined inverse filter, at a level/duration suited
   to measurement rather than just delay detection.

## Out of scope

- Multi-sub optimization (MSO-style seat-to-seat smoothing across subs) — real
  feature, separate design.
- THD analyzer from the same captures — falls out later, not part of this.
- Multirate sub FIR (decimate /8) — already deferred in CHANNEL_ARCHITECTURE;
  unneeded here since subs get no taps.

## Open questions

- Revisit the "no sweeps" decision for the stationary case (see Measurement).
- Where does deconvolution run — browser (preferred above) or device?
- Upload protocol framing over the UART link; file naming/versioning scheme
  and SD cleanup for superseded auto-generated filters.
- Default transition frequency between FIR and biquad territory (fixed
  ~300–500 Hz vs derived from the gate the room actually allows).
- Whether the music render's default budget (10 ms) should be user-visible as
  a number or as a "max phase correction depth" frequency.

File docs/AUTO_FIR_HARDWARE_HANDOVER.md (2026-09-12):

# Auto-FIR: Hardware Session Handover

Written 2026-08-30. The auto-FIR feature is software-complete and committed;
everything below is what the first hardware session needs. Background:
`AUTO_FIR_DESIGN.md` (rationale), `AUTO_FIR_CONTRACTS.md` (wire grammar,
acceptance criteria).

Commits, in order: `7df925f` contracts + acceptance harness → `5aff082`
measurement math (sweep-math.js) → `abecf7a` designKernel → `675b33f`
firmware upload path + sweep command → `9614c0c` sweep HTTP routes →
`2b6e838` the wizard. All verified against the native test suite (175),
the WebUI suite (191), and the mock server — **nothing has touched real
hardware yet**.

## Pre-flight

1. **Back up the config**: download via the Home view's backup button (or
   `GET /backup`) to `ESP/config-backup-<date>-preflash.msgpack` — the
   uploadfs step below wipes it.
2. `WebUI/dist` is current as of 2b6e838 (`npm run build` if in doubt);
   `ESP/esp-web-server/data/dist` is a symlink to it. `data/certs/` holds
   the good mkcert pair from the 2026-08-13 cert resolution — **this Mac's
   data dir is safe to flash** (the phone-trust CA matches).

## Flash sequence

```
pio run -d ESP -e esp32s3 -t uploadfs --upload-port <CH343 port>   # wipes config
pio run -d ESP -e esp32s3 -t upload   --upload-port <CH343 port>
pio run -d Teensy -e teensy41 -t upload
```

- Explicit `--upload-port` always: autodetect can grab the Teensy instead
  of the CH343.
- Opening the CH343 port resets the S3 — check ping/mDNS/curl before any
  serial poking, or the evidence is gone.
- Restore the config (`POST /restore` or the UI button) after uploadfs.
- Known lie: the FIRST `/fir/files` and `/recorder` calls after boot serve
  stale cache defaults — retry once before believing them.

## Test ladder (in order — each rung assumes the previous held)

1. **Boot sanity**: web UI loads over HTTPS from the phone, presets play.
2. **Upload contract tests** (from `WebUI/`):
   ```
   VYBES_API_URL=https://vybes.local npm run test:contract
   ```
   Three new device-gated tests: upload a 512-tap `.bin` → listed with
   exact taps → pool charges 512 → delete; delete-while-referenced → 409;
   bad name / missing file. This exercises the whole HTTP→UART→SD chain.
3. **Sweep smoke test** (short, before trusting a full session):
   ```
   curl -k -X PUT "https://vybes.local/probe/sweep/start?chirpSamples=16384&passes=1&level=30"
   ```
   Expect a `SWEEP START ...` probeEvent on the websocket with the derived
   schedule, one `SWEEP CHIRP` per enabled output, audible sweeps soloing
   each output, then `SWEEP DONE` and normal audio back (click-free ramp).
   `PUT /probe/sweep/stop` must cut it off mid-run.
4. **The wizard**, at the listening seat: FIR section of the active preset →
   "Auto-measure & correct with phone mic…". iPhone: set Control Center
   **Mic Mode → Wide Spectrum** first; HTTPS is required for the mic.
   Defaults are ~3 s sweeps at ~4.5 s spacing — roughly a minute of
   continuous capture for a 6-output rig at 2 passes. In **stage 4 pick the
   target curve** (downward tilt / flat / Harman / B&K / imported) before
   designing — it defaults to −0.5 dB/oct and shares its stored selection
   with the analyzer's auto-EQ, so whatever was last chosen there is what
   comes up here; the dashed line on the predicted-result chart is the curve
   the kernels aim at. Changing the target or the latency budget clears the
   rendered set — press *Design filters* again. Apply lands on a preset
   copy, so the original is untouched.

## Watch items (untested against real hardware)

- **UART under load**: the 16-line ACK window and 5 s per-op timeouts have
  only run against the native fake. A full-pool upload is ~7 s of solid
  UART traffic sharing the line with keepalives/RTA frames — watch for
  `504` (timeout) or `FIRPUT ERR badSeq` (desync), and grab serial logs if
  either appears.
- **ESP heap during upload**: the body stages to a LittleFS temp file while
  a TLS socket sits open; heap-wise this is designed to be flat, but watch
  `minFreeInternal` telemetry during rung 2 anyway.
- **The httpd task blocks** for the duration of each upload — with the
  2-socket TLS ceiling the UI may feel stalled during Apply. Cosmetic, but
  worth knowing before diagnosing it as a hang.
- **Teensy replies moved to `printf`** in slice A (ITCM budget fix) — the
  reply formatting has passed native tests but not real Serial1.
- **Arrival detection windows**: drift estimation searches ±20 ms around
  each nominal slot; physical inter-output path differences beyond that
  (very large rooms / distributed subs) would break arrival matching. The
  wizard's review stage flags low-SNR outputs — believe it.
- **RAM watermarks**: `teensy_size` was clean (RAM2 free-for-malloc
  113,248, unchanged), but check the boot heap telemetry once FIRs load.

## Rollback

The wizard's Apply writes only to a preset copy — deleting that preset and
its `a<gen>-*.bin` files (`DELETE /fir/files?name=`) restores the previous
state exactly. Firmware rollback is `git checkout 3f6d472 -- Teensy ESP`
territory plus reflash; the config backup from pre-flight covers the rest.

## If something needs code changes

The mock server reproduces the whole flow without hardware
(`mock-server` + the `webui-dev-c` launch config); the acceptance suite
(`WebUI/tests/unit/fir-design-acceptance.test.js`) and the wizard's
synthetic E2E test (`fir-wizard.test.js`) are the regression net — keep
them green. The wire grammar is contract-bound: change
`AUTO_FIR_CONTRACTS.md` first, then both sides plus `test_protocol`, never
one side alone.

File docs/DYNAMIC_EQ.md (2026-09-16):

# Dynamic EQ

The shared input EQ (the "preference curve" on the L/R buses, ahead of the routing
matrix) used to be one fixed curve. It is now a curve that follows the volume:
two anchors above, an automatic loudness compensation below.

This document is the contract. The ESP web server, the mock server, the WebUI and
the Teensy firmware all implement the same rules, and the contract suite
(`WebUI/tests/contract/api-contract.test.js`) enforces the HTTP half of them.

## Why

A tuning only sounds right at the level it was made at. Turn it up and the bass a
listener asked for turns into boom; turn it down and the same bass disappears —
the ear's low-frequency sensitivity falls faster than its midrange sensitivity as
level drops (ISO 226 equal-loudness contours). A single stored curve is therefore
a curve for one volume.

The two halves of the problem are not the same problem, so they get different
mechanisms:

* **Above the reference volume** the correction is *taste*, not physics: how much
  less bass a particular system wants when it is playing loud is a property of
  the room, the speakers and the listener. So it is user-configured — a second
  set of gains, and the device crossfades between them.
* **Below the reference volume** the correction *is* physics, and the contours
  say what it should be. So there is nothing to configure: one on/off switch.

## The two anchors

`InputEq` holds up to two band sets, tagged by role:

| role | `spl` tag | meaning |
| --- | --- | --- |
| reference | `0` | what the preset sounds like at `referenceVolume` |
| loud | `1` | what it should sound like at `loudVolume` |
| unused | `-1` | free slot |

(`spl` was a never-implemented "EQ per SPL" field. It is a role tag now; the JSON
key keeps its old name so older backups parse without a rewrite.)

**Band count, frequencies and Qs are shared between the anchors. Only the gains
differ.** That is what makes band-for-band interpolation meaningful at all — two
independently-shaped curves have no correspondence to crossfade along. The ESP
enforces the invariant on every write:

* an edit to a reference point writes its frequency and Q through to the loud set;
* adding a reference band adds a flat one to the loud set;
* removing reference bands trims the loud set with them;
* a write to the loud set carries **gains only**.

`loudVolume == 0` means "no loud anchor": the reference curve plays at every
volume at or above the reference.

## The volume law

The slider is a percent; the Teensy cubes the linear value, so a percent is

```
dB = 60 · log10(pct / 100)          floored at −60 dB
```

| slider | dB | | slider | dB |
| --- | --- | --- | --- | --- |
| 100% | 0.0 | | 50% | −18.1 |
| 89% | −3.0 | | 35% | −27.4 |
| 79% | −6.1 | | 25% | −36.1 |
| 71% | −8.9 | | 16% | −47.8 |
| 63% | −12.0 | | ≤10% | −60.0 (floor) |

The floor keeps 0% finite; below 10% the interpolation and compensation are
already pinned at their extremes anyway.

`volumePctToDb()` in `WebUI/src/eq-math.js` is the reference implementation.

## Interpolation and hold

With `refDb`, `loudDb` and `volDb` the three volumes in dB:

```
t = clamp((volDb − refDb) / (loudDb − refDb), 0, 1)
gain[i] = refGain[i] + t · (loudGain[i] − refGain[i])
```

* At or below the reference anchor, and whenever there is no loud anchor, the
  reference gains play unchanged.
* Between the anchors the two curves crossfade band-for-band, linearly in dB.
* Above the loud anchor the loud curve **holds** — it is not extrapolated. A
  curve extrapolated past its anchor runs away: at 2× the anchor distance a
  −6 dB band becomes −12 dB, and nothing the user ever listened to justifies it.

`dynamicEqGains()` in `WebUI/src/eq-math.js` is the reference implementation.

## Loudness compensation

Below the reference anchor, with `drop = refDb − volDb` (a positive number of dB),
the device applies **two high-shelf filters**:

| corner | gain |
| --- | --- |
| 300 Hz | `−min(15, 0.25 · drop)` dB |
| 60 Hz | `−min(15, 0.25 · drop)` dB |

RBJ audio-EQ-cookbook high shelves with slope S = 1 (`Q = 1/√2`), at the device's
44.1 kHz — the digital shelf, so what the UI draws is what the Teensy runs.

**Two shelves, not one**: the ear's low-frequency sensitivity falls away in two
stages — gently below ~300 Hz, then much faster below ~60 Hz. A single shelf can
fit one of those or the other, not both. 0.25 dB of tilt per dB of level drop is
what matches the contours; the 15 dB cap per shelf stops a very low volume asking
for an extreme tilt (it binds at a 60 dB drop, beyond the useful range).

### Fit against ISO 226:2003

For a reference listening level of 80 phon and drops of 5…40 dB, the shelf pair
tracks the equal-loudness prediction

```
wanted(f) = Lp(f, R − drop) − Lp(f, R) + drop
```

to within **1.27 dB** at every ISO 226 band from 20 Hz to 2 kHz. The physics test
in `WebUI/tests/unit/eq-math.test.js` embeds the standard's `af`/`Lu`/`Tf` table
and asserts a 1.5 dB bound.

The fit is deliberately **low-frequency only**. Above ~2 kHz the contours' shape
depends on the absolute SPL at the listening position, which the device does not
know — it knows a slider percent, not a sound pressure level. Guessing there
would colour the top end on every quiet listen, for a correction that is at most
a dB or so.

### Why cuts, and what a user notices

The compensation is expressed as **cuts above the corners**, never as a boost
below them. A boost would ask for headroom the amplifier may not have, right at
the frequencies that consume it fastest, and would clip the very material it was
supposed to rescue.

The visible consequence: **below the reference volume the mids fall about 0.5 dB
for every dB the slider gives up** (two shelves × 0.25 dB/dB), on top of the
slider's own attenuation. Turning down by 10 dB drops the bass by 10 dB and the
midrange by 15 dB. That is the intended behaviour — the balance is what is being
preserved, not the absolute level — but it is why the device gets quiet faster
with loudness on, and why the switch exists.

The EQ graph draws the compensation **relative to 1 kHz**
(`loudnessCompensationRelDb()`), because on screen it reads as a bass lift, which
is what a listener hears.

## Config schema (v5)

`CONFIG_CURRENT_VERSION` is 5. `Preset.inputEq`:

```jsonc
"inputEq": {
  "enabled": true,
  "sets": [
    { "spl": 0, "points": [ { "freq": 60, "gain": 4, "q": 0.7 } ] },   // reference
    { "spl": 1, "points": [ { "freq": 60, "gain": 8, "q": 0.7 } ] }    // loud (gains differ only)
  ],
  "referenceVolume": 40,   // slider percent 0-100
  "loudVolume": 80,        // slider percent; 0 = no loud anchor
  "loudness": true
}
```

### Migration from v4 and earlier

Applied on boot load *and* on `POST /restore` of an older backup
(`migrate_config` in `ESP/esp-web-server/config.cpp`):

```
referenceVolume = preset.volume
loudVolume      = 0
loudness        = true
```

Anchoring each curve at the level its own preset plays at means the upgrade
reproduces exactly what the old static curve did: no loud anchor to interpolate
toward, and nothing below the reference until the volume is actually turned down.

## HTTP API

All routes take `?preset_name=`, 404 on an unknown preset, and broadcast their
change over `/live-updates` so other open UIs stay in sync.

| route | body | reply |
| --- | --- | --- |
| `PUT /preset/eq/anchors` | `{ referenceVolume, loudVolume }` | 200 `eqAnchorsChanged` |
| `PUT /preset/eq/loud` | `{ gains: [...] }` | 204 (broadcasts `eqLoudChanged`) |
| `DELETE /preset/eq/loud` | — | 200 `eqLoudChanged` |
| `PUT /preset/eq/loudness?enabled=1\|0` | — | 200 `eqLoudnessChanged` |

* **anchors** — percents, 0-100 (400 outside that); an absent key keeps its stored
  value. `loudVolume <= referenceVolume` is stored as `0`, not rejected: it is an
  anchor with no range to interpolate across, which is the same thing as none.
* **loud** — gains align to the reference bands. Longer than the reference band
  count is a 400; shorter leaves the remaining bands flat. The set is created by
  mirroring the reference bands, so it never has to be described.
* **DELETE loud** — removes the set *and* clears `loudVolume`. The reference curve
  is untouched.
* **loudness** — accepts `1`/`0` (and `on`/`off`, like its sibling toggles).

The existing reference routes (`PUT /preset/eq`, `PUT /preset/eq/point`) keep the
loud set mirrored as described under *The two anchors*.

### Websocket messages

```jsonc
{ "messageType": "eqAnchorsChanged",  "presetName": "…", "status": "ok",
  "referenceVolume": 40, "loudVolume": 80 }
{ "messageType": "eqLoudChanged",     "presetName": "…", "status": "ok",
  "loudVolume": 80, "gains": [8, -6, 5] }          // gains: [] = anchor removed
{ "messageType": "eqLoudnessChanged", "presetName": "…", "status": "ok",
  "loudness": true }
```

`eqLoudChanged` carries gains only — the bands always come from the reference
anchor, so a receiver rebuilds the loud set from its own copy of them.

## UART commands

Added to `ESP/esp-web-server/teensy_protocol.h`:

```
setInputEqLoudGain <band> <gain>        # loud-anchor gain for one band, dB
setInputEqAnchors  <refPct> <loudPct>   # 0-100; loud 0 = no loud anchor
setLoudness        <0|1>
```

The Teensy holds the volume law, the interpolation and the shelf pair: the ESP
sends anchors and gains, never a computed curve, so the DSP can re-evaluate on
every volume change without a round trip.

`resetInputEq <fromBand>` zeroes the loud gains from that band too, so trimming
the reference curve needs no extra traffic.

**Ordering.** On preset activation and on every loud write, gains go first and
anchors second: the Teensy only interpolates once it has a loud anchor, so a
half-sent loud curve is never audible. Activation is:

```
setInputEq × n  →  resetInputEq n  →  setInputEqLoudGain × n  →
setInputEqAnchors  →  setLoudness  →  setVolume
```

## Web UI

In the preset editor's EQ section (`WebUI/src/components/shared/EQSection.vue`):

* **An anchor chip strip** — `Reference NN%`, then either `Loud NN%` or a dashed
  `+ Loud anchor` when there is none (disabled until the volume is above the
  reference). The chips are the graph's tab strip as well as its anchor display:
  the selected chip is the curve the graph edits, so there is no separate
  *Editing* control. In *Loud* mode the graph edits gains only: frequency and Q
  inputs are disabled, node drags are vertical, REW import and add/delete band
  are hidden, and a one-line hint says why.
* **Actions for the selected chip**, right-aligned on the same row: *Set to
  current* for the reference, *Move to current* and *Remove* for the loud anchor.
  A new loud anchor starts as a copy of the reference curve, so placing it
  changes nothing audibly until its gains are edited.
* **One hint line** under the strip, carrying whichever explanation fits the
  state: where the curve is tuned, why the loud anchor cannot be placed yet, or
  the range it interpolates across.
* **Loudness compensation below reference** — the on/off switch, with a one-line
  explanation.
* On the graph, a dashed **"Now at NN%"** curve shows what is actually playing —
  the interpolated gains plus the relative loudness compensation — whenever that
  differs from the curve being edited. The active preset's live volume arrives
  over the websocket (`volumeChanged`), so the dashed curve tracks the slider.

The per-output PEQ shares the same `ParametricEQ.vue` component and is untouched:
every dynamic-EQ behaviour is behind the `gainsOnly` / `overlayDb` props, which
default off.

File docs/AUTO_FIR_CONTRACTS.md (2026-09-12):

# Auto-FIR Contracts (Phase 0)

Status: **binding interface contracts** for the auto-FIR implementation slices,
2026-08-30. The rationale lives in `AUTO_FIR_DESIGN.md`; this document is what
each implementation slice is built and verified against. Changing a contract
here means re-agreeing it first — implementations conform to this file, not
the other way around.

Slices and file ownership (an implementer touches nothing outside its list):

| Slice | Scope | Files |
|---|---|---|
| A | FIR file upload/delete: HTTP + UART + SD | `ESP/esp-web-server/` (api_fir, teensy_comm, teensy_protocol.h, web_server), `Teensy/fir_filters/` (new FirUpload module + command router hookup), `Teensy/test/` protocol/router tests, `WebUI/tests/contract/` |
| B | Measurement + design math in the browser | `WebUI/src/sweep-math.js`, `WebUI/src/fir-design.js`, `WebUI/tests/unit/` (their tests) |
| C | Wizard UI (later phase) | `WebUI/src/` views/components/stores; consumes A's routes and B's modules |
| — | Teensy measurement sweep command | With A (same protocol files); spec below |

Shared constants (already in source, restated for reference): tap pool
`FIR_TAP_POOL` = 12288, charge quantum `FIR_POOL_CHARGE_QUANTUM` = 128,
`NUM_OUTPUTS` = 8, `FIR_FILENAME_LEN` = 63, UART lines ≤ `TEENSY_MSG_MAX` = 80
bytes at 115200 baud, device sample rate 44117.647 Hz (nominal 44100 in the
probe schedule contract).

---

## Slice A — FIR file upload and delete

### HTTP (ESP)

**`POST /fir/upload?name=<file>`** — body is the raw file bytes.

- `name` must pass `isValidFirFilename` (≤ 63 chars, no spaces/control chars)
  and end in `.bin`, `.wav`, or `.txt`. The wizard uploads `.bin` only (raw
  little-endian float32 taps, no header — exact `size/4` tap accounting).
- Size: 4 ≤ size ≤ 51,200 bytes; a `.bin` size must be a multiple of 4.
- The body is **streamed** to the UART in chunks as it arrives — the ESP never
  buffers the whole file (heap discipline; the /restore stack-size lesson
  applies: this handler declares its own httpd stack size ≥ 10240).
- Success: `200 {"name": "...", "size": N, "taps": N}` — taps as reported by
  the Teensy's `FIRPUT OK`. Before responding, the ESP re-reads the SD file
  list **and waits for the reply to land**, so an immediate `GET /fir/files`
  sees the new file. Merely *requesting* a refresh is not enough: reads are
  served from whatever is cached at that instant and the reply arrives later
  on the loop task, which left the next read one refresh behind.
- Errors: `400` bad name/size, `409 {"error":"recording"}` while the recorder
  is busy (SD contention), `409 {"error":"busy"}` if another upload is in
  flight (one at a time), `502` with the Teensy's `FIRPUT ERR` reason if the
  device rejects it, `504` on UART timeout (no ACK for 5 s).

**`GET /fir/files`** serves the cache and kicks an asynchronous refresh for
the next read — except on the very first read after a boot, when nothing has
ever been cached: an empty cache is indistinguishable from "the card has no
FIR files", so that one call waits for a real answer rather than lying.

**`DELETE /fir/files?name=<file>`**

- `409 {"error":"referenced","presets":[...]}` if any preset's output
  references the name; otherwise relays `firDelete`, re-reads the cached list
  and waits for it (as upload does), returns `200 {"name":"..."}`. `404` if
  the device reports no such file. Same `409 recording` guard.

### UART grammar (ESP → Teensy; replies Teensy → ESP)

Line-based like every other command; every line ≤ 80 bytes.

```
firPutBegin <name> <size> <crc32>     ->  FIRPUT BEGIN <name>
                                       |  FIRPUT ERR <reason>
firPut <seq> <base64>                 ->  FIRPUT ACK <seq>      (every 16th line and the final line)
                                       |  FIRPUT ERR <reason>   (aborts the transfer)
firPutEnd                             ->  FIRPUT OK <name> <size> <taps>
                                       |  FIRPUT ERR <reason>
firPutAbort                           ->  FIRPUT STOP
firDelete <name>                      ->  FIRDEL OK <name> | FIRDEL ERR <reason>
```

- `seq` counts from 0, decimal. Base64 payload ≤ 60 chars (45 raw bytes), so
  a full-pool file is ~1,100 lines (~7 s at 115200 baud).
- Flow control: the ESP sends at most 16 lines beyond the last ACK'd `seq`.
  **The receiver's UART RX buffer must hold that whole window** (16 lines x
  75 bytes = 1,200 B; `FIR_PUT_MAX_IN_FLIGHT_BYTES` in `teensy_protocol.h`,
  which `fir_filters.ino` static_asserts `espRxBuffer` against). A buffer
  smaller than the window drops a line under burst and the transfer dies
  with `badSeq` — a 512-byte buffer failed 100% of kernels over ~1,500 taps
  on hardware (2026-08-31) while passing every native test, since the fake
  stream has no buffer limit.
- `crc32` is IEEE 802.3 (reflected, init `0xFFFFFFFF`, final XOR
  `0xFFFFFFFF`), 8 lowercase hex chars, computed over the raw file bytes.
- Teensy writes to `upload.tmp` on the SD, and on `firPutEnd` verifies byte
  count and CRC, removes any existing target, renames, then replies. A
  failed verify leaves the SD exactly as before (`upload.tmp` removed).
- `ERR` reasons (single tokens): `badName`, `badSize`, `badSeq` (gap or
  repeat), `badB64`, `crc`, `sd`, `noSpace`, `busy` (recording or another
  transfer active), `state` (firPut/firPutEnd without Begin).
- **The reason reported for a failed transfer is the *first* `ERR` of that
  transfer, not the last.** When the Teensy aborts it resets its session, so
  every line already in flight draws its own `ERR state`; reporting the last
  one would mask the real cause behind `state` for every failure. The ESP
  latches the first error per single-flight op (`firFirstErrReason` in
  `teensy_comm.cpp`).
- Uploading never touches running filters. Overwriting a name currently
  loaded by the active preset leaves the loaded coefficients stale until the
  next assignment or preset activation — the wizard uses fresh versioned
  names (`a<gen>-<label>.bin`, e.g. `a3-woofer-l.bin`) so this path is never
  exercised in practice.

### Tests slice A must ship (parity on both sides — the standing trap)

- Teensy native: command-router/protocol tests for the full grammar —
  happy path, seq gap, CRC mismatch, oversize, abort, mid-transfer `busy`,
  and that `FIRPUT`/`FIRDEL` reply lines parse under the same rules as the
  existing reply grammar.
- ESP side: the protocol constants and framing land in `teensy_protocol.h`
  so the existing parity checks cover them.
- WebUI contract test (`tests/contract`, device-gated like the rest): upload
  a 512-tap `.bin` → `GET /fir/files` lists it with taps = 512 → pool math
  charges 512 → delete → gone; delete-while-referenced returns 409.

---

## Teensy measurement sweep command (with slice A)

The delay probe's machinery is reused (ProbeSource waveform recurrence,
per-output soloing, PROBE event relay), parameterized for measurement:

```
startSweepProbe <mask> <level%> <f0> <f1> <chirpSamples> <nPasses>
```

Replies (relayed to the web UI like probeEvent):

```
SWEEP START <mask> <nPasses> <preRoll> <spacing> <chirpSamples> <f0> <f1> <fade>
SWEEP CHIRP <slot> <ch>
SWEEP WARN unrouted <ch>
SWEEP DONE | SWEEP STOP | SWEEP ERR <reason>
```

- Waveform: the same double-precision log-sweep recurrence as ProbeSource,
  raised-cosine fades of `<fade>` samples each end, so the browser reference
  stays analytically exact.
- Slot order: outputs ascending, then the same list repeated `nPasses` times
  (**not** reversed like the delay probe — pass-to-pass comparison of the
  *same* output is the consistency/drift check).
- `spacing ≥ chirpSamples + 66150` (≥ 1.5 s IR tail at device rate).
- Defaults the wizard requests: f0 = 20 Hz, f1 = 20000 Hz, chirpSamples =
  131072 (~3 s), nPasses = 2.
- The values echoed in `SWEEP START` are the single source of truth for the
  JS reference generator — the browser never assumes compiled-in constants.
- The Teensy changes nothing about preset state: the **wizard** turns
  `firEnabled` and `inputEq.enabled` off for the session via the existing
  APIs and restores them after (input EQ off is an amendment to
  AUTO_FIR_DESIGN's stage 1: it is room-band correction that re-runs after
  the wizard, so it must not be baked into the driver measurement; output
  PEQ and crossovers stay active as designed).

---

## Slice B — measurement + design math

Interfaces are pinned by the stubs in `WebUI/src/sweep-math.js` and
`WebUI/src/fir-design.js` — JSDoc there is normative (units, array layouts,
zero-time conventions). Acceptance is the currently-skipped suite
`WebUI/tests/unit/fir-design-acceptance.test.js`, which runs against the
synthetic-system simulator in `WebUI/tests/helpers/synth-system.js`.
**The simulator and acceptance thresholds are verification harness — slice B
does not modify them.** If a threshold is genuinely wrong, that's a contract
change (top of this file).

Numbered acceptance criteria (mirrored in the test file):

1. **Deconvolution**: a simulated capture of a pure 5 ms delay recovers an IR
   peak at 5 ms ± 0.1 ms, ≥ 40 dB above the off-peak background.
2. **Drift**: an injected 80 ppm clock offset is estimated within ± 5 ppm
   from the two-pass spacing, and resampling by the estimate re-aligns the
   passes to within 1 sample.
3. **Magnitude correction**: on a synthetic system with two resonances
   (+6 dB @ 400 Hz Q 2, −4 dB @ 2.5 kHz Q 3) inside a 300 Hz–8 kHz band, the
   corrected system (kernel ⊛ system, computed by the test's own FFT)
   **matches the target** within ± 1 dB across the band; the kernel's own
   gain outside the band stays within ± 1.5 dB of unity. Flat is the
   `targetDb`-omitted instance of that criterion; **3b** (amended
   2026-09-12, when stage 4 gained a target selector) repeats it on the same
   plant against a −1 dB/oct tilt, to the same tolerance, and checks the
   kernel really carries the extra octave slope. Targets are resolved by
   `WebUI/src/target-curves.js` `targetDbOnFreqs` — the same function the
   analyzer's auto-EQ aims at, so a house curve means one curve device-wide.
4. **Minimum-phase render** (budget 0): ≥ 50% of kernel energy in the first
   64 samples, and corrected-system group delay ≤ 1 ms across the band.
5. **Latency budget**: with budget B samples, the kernel's bulk lead is
   exactly B ± 2 samples, and excess-phase deviation of the corrected system
   is reduced ≥ 70% relative to uncorrected over the band the budget reaches
   (f ≥ 1/(B/rate)).
6. **Presence cap**: a +6 dB synthetic error at 2 kHz with a ± 3 dB cap in
   1–5 kHz yields a kernel applying no more than 3 dB of cut there.
7. **Tap budget**: on the design doc's worked topology (3-way stereo +
   2 subs), the plan zeroes subs and disabled outputs, gives every corrected
   output ≥ 256 taps in multiples of 128, allocates symmetrically for
   symmetric passbands and monotonically in 1/fLo (woofer/mid ratio in
   [2, 4.5]), and fills the pool to within 6 quanta of pool − 2×128 reserve
   without exceeding it. (The design doc's 512/1,536/3,584 illustration is
   one valid plan, not a pinned answer.) Suggested algorithm: the largest
   common support factor c such that Σ quantize₁₂₈(clamp(c·rate/fLo, 256,
   8192)) fits the budget — but the test constrains outcomes, not the
   algorithm.
8. **Encoding**: `encodeFirBin` round-trips: bytes/4 taps, little-endian
   float32, exact values.
9. **Gated response fidelity** (added 2026-08-30 after integration review
   found `gatedResponse` unconstrained by 1–8): on reflection-free systems it
   matches the harness's ungated view — magnitude *shape* within 1.5 dB
   (including when the IR peak sits near the buffer start, where the
   analysis window extends before time zero), excess phase ≤ 0.2 rad RMS on
   a minimum-phase system, within 0.3 rad RMS of the harness on an allpass
   system — and on a system with a 6 ms reflection, the gated HF curve
   (≥ 2 kHz, 8-cycle windows) moves ≤ 1 dB while the ungated comb is ≥ 4 dB.
10. **predictCorrected invariances**: a delta kernel changes neither
    magnitude (±0.1 dB-ish) nor excess phase (≤ 0.05 rad RMS); a pure-delay
    kernel reads as bulk delay, not excess phase or magnitude.

Notes for the implementer: the radix-2 FFT in `delay-align.js` may be
extracted into a shared module (that refactor is in-scope for B; keep
`delay-align.js` tests green). Everything must be pure functions on typed
arrays — no DOM, no Web Audio — so it all runs under vitest/node.

---

## Slice C — wizard UI (contract sketch; finalized when B lands)

Stages per AUTO_FIR_DESIGN §User workflow. Hard requirements: budget screen
before any audio (uses `planTapBudget` + `GET /preset/fir/pool`); measurement
uses `startSweepProbe` and captures in one getUserMedia session; preset flags
(`firEnabled`, `inputEq.enabled`) saved/restored around the session; apply
path = copy preset → `POST /fir/upload` per output → `PUT /preset/output/fir`
→ delays via existing route; every capture reuses the analyzer's capture-chain
readback and cal-profile plumbing. Development against mock-server +
stubbed getUserMedia (the established trick).

---

## Acceptance gates (run by the integrator, not the slices)

1. `pio test -e native` — full suite, both firmwares build (`teensy41`,
   `bench`, ESP envs).
2. `npm test` in WebUI — including the acceptance suite once B lands
   (the skips get removed as part of B's delivery).
3. `git status` scoped per slice — no files outside the ownership table.
4. Contract tests against real hardware before any flash is called done.

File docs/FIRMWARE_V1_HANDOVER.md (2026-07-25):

# Firmware V1 Handover: ESP32-S3 + Teensy work

Status as of 2026-07-26: the WebUI, mock server and API contract for the
8-output V1 architecture (docs/CHANNEL_ARCHITECTURE.md) are **done and
verified**. The **ESP32-S3 work below is implemented** (compiles for
esp32s3 + esp32dev; contract suite passes against the mock but has not yet
been run against hardware). The **Teensy work below is implemented too**
(compiles for teensy41; all 62 host-native tests pass, including the V1
protocol round-trip and the new crossover-response suite). Remaining:
hardware bring-up, the benchmarks flagged at the end of the Teensy section,
and a hardware contract run.

## Sources of truth (in priority order)

1. **WebUI/tests/contract/api-contract.test.js** — the executable API spec.
   It runs hermetically against the mock (`npm run test:contract` in WebUI/)
   and against a real device (`VYBES_API_URL=http://vybes.local npm run
   test:contract`). The ESP implementation is finished when the suite passes
   against hardware. Every endpoint, status code, clamp/reject behavior and
   websocket broadcast shape is asserted there.
2. **mock-server/server.js + mock-server/templates.js** — reference
   implementation. Template definitions (outputs, crossover points, locked
   flags, min/max ranges, hpFloors) port from templates.js verbatim.
3. **docs/CHANNEL_ARCHITECTURE.md** — design rationale, config schema,
   safety model, Teensy graph plan.

## Constants (must match everywhere)

| Constant | Value |
|---|---|
| NUM_OUTPUTS | 8 |
| MAX_CROSSOVER_POINTS | 4 |
| MAX_OUTPUT_PEQ | 10 per output |
| MAX_INPUT_PEQ | 15 per SPL set (MAX_PEQ_SETS 3, unchanged) |
| FIR_TAP_POOL | 12288 taps shared across outputs |
| Output gain | -40..+10 dB (clamped) |
| Delay | 0..20000 us per output (rejected outside) |
| Crossover types | LR2, LR4, BW2 |
| Templates | 2.0, 2.1 (default), 2.2, 2way-sub, 3way, 3way-2sub |

## ESP32-S3 work (DONE 2026-07-26)

Decisions made during implementation that the Teensy work must honor:

- **FILES listing carries sizes**: the `getFiles` reply lines become
  `"name size"` (bytes). The ESP parses the optional second token
  (teensy_comm.cpp getCachedFirFileSize) and degrades gracefully to
  name-only lines from older firmware (files then count as the default
  tap estimate).
- **Tap estimation on the ESP** (api_fir.cpp): `.bin` = size/4 (raw
  float32 taps), any text format = size/12 (~bytes per coefficient line),
  unknown/unsized file = flat 2048 (matches the mock). The Teensy's
  load-time pool check remains the authoritative backstop.
- **Disabled output = muted**: the ESP sends `setOutputMute <ch> 1` when
  an output is disabled (effective mute = mute || !enabled); the Teensy
  needs no "enabled" concept.
- **Legacy CMD_\* defines** (setDelays, setEq, setCrossoverFrequency, …)
  were deleted from teensy_protocol.h when the Teensy protocol + tests
  moved to the setOutput* commands (done, see below) - the round-trip test
  asserts the two command tables cover each other, so both sides changed
  together.
- ESP constants: MAX_PRESETS 12 and PRESET_NAME_MAX_LEN 48 (the contract
  suite generates ~41-char names and holds ~8 presets concurrently);
  Teensy command queue QUEUE_SIZE 200 (a full V1 sync is ~180 commands).
- Hardware contract runs: the FIR-pool tests only pass if the SD card
  carries files whose derived tap counts match the mock's map
  (fir_room1/2 = 4096 taps, fir_speaker1/2 = 2048, fir_flat = 1024).

- **config.h/cpp rework**: replace the left/right/sub structs with
  `Output outputs[NUM_OUTPUTS]`, `CrossoverPoint crossovers[4]`, inputEq
  (rename of preference_curve sets), per-preset `template`, `delaysEnabled`,
  `firEnabled`. Schema starts at CONFIG_CURRENT_VERSION 1 for the new
  hardware, but keep the version field + a migrate hook wired from day one.
- **Template factory**: port templates.js (labels, sources, xover refs,
  locked flags, ranges, hpFloors). POST /preset?action=create&template=…
- **New/changed endpoints** (see contract suite for exact shapes):
  - GET /templates, GET /preset (V1 shape + firPool), GET /preset/fir/pool
  - PUT /preset/crossover?id=&frequency=&confirm= and
    /preset/crossover/enabled?id=&enabled=&confirm=
  - PUT /preset/output/{label,enabled,source,gain,mute,invert,delay,filter,
    eq,eq/point,fir}?output=0..7
  - Kept: /preset/eq* (input EQ), /preset/delay/enabled, /preset/fir/enabled,
    preset CRUD, all system endpoints (/status, /volume, /mute*, /gains/input,
    generator, RTA).
  - Removed (no longer served): /preset/delay?speaker=, /preset/fir?speaker=,
    /preset/gains, /gains/speaker usage by the UI (endpoint may stay for
    remote/button code until that is reworked).
- **Safety enforcement lives on the ESP** (the UI only mirrors it):
  - Locked crossover point writes without confirm=true → 409 with
    `{"locked": true}`.
  - Any change leaving an enabled output's effective HP below its hpFloor →
    409, including crossover bypass and per-output filter edits, regardless
    of confirm.
  - FIR loads exceeding the tap pool → 409 with `{used, total}`. Tap counts
    per file come from Teensy-reported file sizes (decided: see the
    "name size" listing + tap estimation notes above).
  - Structural edits (source, hp/lp, output enabled) flip template→"custom"
    and report `"template": "custom"` in the outputChanged payload once.
- **Websocket broadcasts**: outputChanged {output, changes, firPool?,
  template?}, outputEqChanged, crossoverChanged {id, crossoverFreq},
  crossoverEnabledChanged {id, crossoverEnabled}; legacy delayChanged /
  firChanged / eq shapes for input EQ unchanged.
- **Teensy sync**: updateTeensyWithActivePresetParameters resolves crossover
  references to concrete per-channel frequencies before sending - the Teensy
  never sees crossover ids or templates.

## Teensy work (DONE 2026-07-26, benchmarks pending)

Implemented as planned; decisions made along the way:

- **Serial protocol**: TeensyCommands.h + teensy_protocol.h moved to the
  output-indexed V1 set (27 commands); the legacy 3-channel CMD_\* defines
  are gone and test_protocol covers the new set. `setSpeakerGains` is still
  accepted (the ESP's remote/button path sends it) but is a no-op on the
  Teensy - global L/R/sub gains have no meaning in the 8-output model.
  SerialCommandRouter MAX_COMMANDS went 24 -> 32.
- **Audio graph** (fir_filters.ino): per-output arrays built in a loop
  (source AudioMixer4 -> CrossoverFilter -> PEQProcessor (10 bands) ->
  AudioFilterFIRFloat -> AudioEffectDelay -> AudioAmplifier), wired with
  dynamic AudioConnection::connect(). Octal I2S 0-7 map 1:1; SPDIF mirrors
  outputs 0/1. Outputs boot silent (source gains 0) until the ESP syncs.
- **Crossover is a new float32 SVF cascade** (CrossoverFilter +
  CrossoverMath, LR2/LR4/BW2), not the stock q31 AudioFilterBiquad - sub
  crossovers live at 30-120Hz where the fixed-point biquad gets noisy, and
  the firmware already runs its PEQ on the same (host-verified) Cytomic SVF
  topology. test_crossover_math asserts -6dB/-3dB corners, slopes, and that
  LR4 HP+LP sums flat.
- **Bypass lives inside the objects**: crossover/PEQ/FIR pass through when
  idle, delay bypass = delay time 0. No patchcord swapping remains.
- **Gain/invert/mute/volume** collapse into the per-output amp; one smoothed
  ramp (updateAudioVolume) covers all of them, so every change is click-free.
- **FIR tap pool**: shared 12288-tap budget enforced at load. Oversized
  loads are *rejected*, not truncated (FIRLoader grew a truncateToMax=false
  mode), and the Teensy relays "ERROR FIR pool exceeded: <file> needs <n>
  taps, <left> of 12288 left" over the ESP link. Each filter is cleared
  before reload so peak heap holds one engine (~200KB at the pool limit),
  not two. FIRLoader also gained `.bin` (raw float32) support to match the
  ESP's size/4 tap estimate.
- **FIR group-delay alignment stays active when user delays are toggled
  off** - it corrects a FIR artifact, it isn't a user delay (the old
  firmware's patchcord bypass dropped both).
- **getFiles** replies with `"name size"` lines (the V1 listing the ESP
  parses for tap estimates).
- **Input EQ unchanged**: peqLeft/peqRight on the L/R buses, 15 bands,
  boost compensation via the pre-EQ amps. The per-output PEQs have no boost
  compensation - output gain staging is explicit in the channel strip.
- **Benchmarks still required before trusting the numbers** (flagged in the
  design doc): AudioMemory is sized at 480 blocks for the worst case (whole
  pool on one output => ~139ms compensation on the other seven, plus the
  20ms user cap); verify on hardware, along with CPU headroom for 8
  concurrent fast-convolution engines (previous builds only ever ran 3).

## Suggested order

1. ESP config structs + template factory + GET endpoints; run the contract
   suite against the device early and often (it creates/deletes its own
   contract-test-* presets and restores globals).
2. ESP write endpoints + safety enforcement + broadcasts (suite green).
3. Teensy protocol + graph arrays behind the existing 3 outputs first
   (channels 3-7 silent), then full 8-channel bring-up.
4. FIR pool + benchmarks.

## Loose ends (UI side, for context)

- Stereo link groups and a crossover/PEQ response overlay on the RTA are
  designed but deliberately deferred (stage 6+ in CHANNEL_ARCHITECTURE.md).
- The WebUI work is uncommitted on main as of this writing.
- mock-server keeps /gains/speaker and speakerGains in /status for the old
  firmware's sake; the UI no longer calls them.

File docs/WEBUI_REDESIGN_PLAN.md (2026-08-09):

# WebUI Design Refresh — Implementation Plan

Outcome of a design audit (2026-07-26) of the Vue app in `WebUI/`, run against the mock
server at desktop (1280px) and phone (375px) widths. This plan covers the accepted
findings. All work is frontend-only; no ESP/Teensy/API changes.

## Explicitly deferred (do NOT implement)

- **Editing non-active presets from Home.** The API supports it, but the current
  UX guarantees you always hear what you're editing. Deferred pending product decision.
- **Input-source signal-presence indicators / mixer metaphor.** Needs investigation
  of what per-input data the firmware can stream.

## Verification baseline

- `cd WebUI && npm run test` (vitest unit tests) must pass before and after.
- `npm run test:contract` must pass (starts the mock server itself).
- Visual checks against the mock server (`node mock-server/server.js`, port via `PORT`)
  with `npm run dev` at 375px and 1280px widths.
- No API surface changes: `api-client.js` request/response shapes stay untouched
  (moving/renaming its *call sites* is fine).

---

## Phase 1 — Design tokens & theme unification

The app currently has three palettes: the Tailwind `vybes-*` theme (gray-800/900
surfaces, blue #3b82f6, amber #f59e0b), ParametricEQ's private palette
(#161b22/#1a2029 surfaces, amber #f5c04e, slate #8b96a8, tabular monospace numerals),
and AnalyzerView's hardcoded hexes (#0088ff, #22c55e, #333, #666). The EQ palette is
the best of the three; promote it to the app-wide theme.

1. **Redefine the CSS variables in `src/style.css`** (single source of truth; keep
   `tailwind.config.js` mapped to the same values):
   - Surfaces (from the EQ's richer, cooler ramp):
     - `--vybes-dark` (page bg): `#10141a`
     - `--vybes-dark-element` (card): `#161b22`
     - `--vybes-dark-card` (nested card / raised): `#1a2029`
     - `--vybes-dark-input` (inputs, slider tracks): `#222a35`
     - `--vybes-border`: `rgba(148, 168, 196, 0.16)` — add a solid fallback token
       `#3a4451` where alpha can't be used.
   - Text: `--vybes-text-primary: #e5ebf3`, `--vybes-text-secondary: #8b96a8`
     (bump any place secondary lands on small text below 12px to primary, see Phase 3).
   - Accents: keep blue `#3b82f6`/`#2563eb` as **interactive/primary**; unify amber
     to the EQ's `#f5c04e` (replaces `#f59e0b`/`#fbbf24`) as **live/active state**.
   - Keep the aliases in `tailwind.config.js` (`vybes-blue`, etc.) pointing at the
     new values so existing classes keep working.
2. **Accent semantics — apply consistently:**
   - Blue = interactive: primary buttons, slider thumbs/values, links, selected
     nav item, selected preset, selected tab.
   - Amber = "currently in effect": Active preset badge, enabled-section state,
     the wordmark. Change the preset-editor active tab underline from amber to blue
     (it's a selection, not a live state).
3. **Replace AnalyzerView's hardcoded colors** with tokens/Tailwind classes:
   source trace `#0088ff` → `#3b82f6` (vybes-primary); grid `#333`/labels `#666` →
   the same grid/label colors ParametricEQ uses (`rgba(148,168,196,…)` ramp, `#8b96a8`
   labels). Mic green `#22c55e` can stay (semantic "live" green) but reference it
   via one place.
4. **ParametricEQ.vue**: swap its hardcoded surface hexes to the new shared
   variables (they're the same values now — the point is one source of truth).
   Its amber `#f5c04e` becomes the theme amber automatically.
5. **Font stack**: change to `system-ui, -apple-system, 'Segoe UI', sans-serif` in
   both `style.css` and `tailwind.config.js`. Add `font-variant-numeric: tabular-nums`
   utility usage for all numeric readouts (slider values, chips, FIR pool counts).

## Phase 2 — Layout & use of space

6. **Cap content width on control pages.** Home, Tools, and the preset editor's
   Tuning tab wrap their content in `max-w-3xl mx-auto` (Channels tab and Analyzer
   keep full container width — charts and the channel grid benefit from it).
   Keep the existing edge-to-edge (`px-0`, `rounded-none`) treatment on mobile.
7. **Home becomes two-column at `lg:`**: left column = Presets, Volume, Speakers,
   Mute/Dim; right column = Input Source. (Within the capped width from #6 this
   means `lg:grid lg:grid-cols-2 lg:gap-4` with the cards distributed — use
   `max-w-5xl` for Home instead of 3xl so two columns breathe.)
8. **Move Backup/Restore off Home** into the Tools page (new "Configuration" card
   there — Tools is the utility page and already exists; do NOT add a fourth nav
   tab for two buttons).
9. **Tools grid**: `lg:grid-cols-3` → `sm:grid-cols-2` (there are only 2–3 cards).
10. **Speakers card**: replace the `justify-between` + `w-1/3` flex-wrap with
    `grid grid-cols-2 sm:grid-cols-3 gap-3` so Left/Right/Subwoofer align cleanly.

## Phase 3 — RangeSlider redesign (the highest-leverage component)

11. Restructure `RangeSlider.vue` to a single header row + full-width slider:
    - Row 1: label (left, secondary text) … **value + unit** (right, blue,
      tabular-nums, primary text size).
    - Row 2: the range input, full width. No side-by-side number box.
    - The value readout becomes a **tap/click-to-edit** control: clicking it swaps
      in a small `type="number"` input (`inputmode="decimal"`, auto-focused,
      select-all; Enter/blur commits, Escape cancels). Keep the same
      clamping/rounding behaviour as today (`emitRoundedValue`).
    - Slider thumb: 20px (from 16px) with a `sm:` down-size to 18px on desktop
      pointer devices if desired; keep the focus ring.
    - Accessibility: the number input gets `:aria-label="label"`; the slider keeps
      its `<label for>`.
12. **One value formatter.** Add `formatValue(value, unit, decimals)` to
    `src/utilities.js`: non-breaking space between number and unit ("0 dB",
    "77 %" → use "%" without space, "1000 Hz", kHz collapsing like the EQ chips
    for Hz values ≥ 1000). Use it in RangeSlider's readout, FirPoolBar, and the
    preset editor's "Taps used" line. Sweep the `unit=" Hz"` / `unit="dB"` props
    for consistency (`unit="Hz"`, `unit="dB"`, `unit="%"`).
13. **Q factor display**: 2 decimals (not 3), consistent with the EQ drag readout.

## Phase 4 — Component fixes

14. **ModalDialog.vue** (bug): `position: absolute` → `fixed` (centres in the
    viewport regardless of scroll). Add: Escape-to-close, `role="dialog"`
    `aria-modal="true"` with `:aria-label="title"`, and focus handling (focus the
    dialog on open, return focus on close; a simple Tab wrap within the dialog is
    enough — no dependency).
15. **Mute → Dim.** Rename the Home card title to "Dim", slider label stays
    "Volume reduction", toggle label "Dim". While active, show a persistent amber
    pill ("Dimmed") in the top bar next to the brand (both desktop nav and a
    compact indicator on mobile — reuse the offline-banner slot area, not a new
    banner). Drive it from the existing `/status` fetch + websocket `muteChanged`
    messages if broadcast (check api-client; if no live message exists, App.vue may
    poll status once on mount and HomeView emits through a tiny Pinia store or the
    apiClient's existing connection — pick the simplest working wiring; a shared
    `systemStore` (Pinia) holding mute state that HomeView and App.vue both use is
    acceptable).
16. **Touch targets ≥ 44px** on interactive icons:
    - Preset-edit pencil: enlarge hit area (`p-2.5`, icon `w-5 h-5`) and add
      `aria-label`.
    - `btn-icon` (rename/copy/delete in the editor header): `p-2.5`, icons `w-5 h-5`.
    - CollapsibleSection headers already have large hit areas — fine.
17. **ToggleSwitch a11y**: add an `ariaLabel` prop applied to the checkbox input;
    set it at every call site that passes no visible `label` (section toggles:
    "Enable EQ", "Enable FIR filters", …; ChannelStrip enable: "Enable output N").
18. **Home error banner**: make it dismissable (click, with a small ✕) — same
    pattern as the preset editor's banner.
19. **Number inputs**: add `inputmode="decimal"` in `InputGroup.vue` when
    `type="number"`.
20. **SpeakerDelayInput**: remove the double label ("Delay" heading + "Delay (µs)"
    label + nested card). Render as a plain labelled row like other inputs:
    label = `title` + " (µs)", no nested `bg-vybes-dark-element` card.

## Phase 5 — Channels tab restructure

21. **ChannelStrip becomes a collapsible accordion item.**
    - Collapsed header (always visible): index, label, enable toggle, and a
      one-line summary in secondary text: source · HP · LP · gain · delay ·
      FIR? · PEQ count (e.g. "Left · HP 80 Hz · LP off · 0 dB · 2 PEQ").
      Disabled channels show just index + label + toggle (as today).
    - Expanded: current strip contents. **PEQ stays collapsed-by-default inside**
      (as today via CollapsibleSection).
    - Default state: all collapsed. Expanding one does NOT auto-close others on
      desktop; on mobile (`< sm`) opening a strip closes the previously open one.
    - Keep the store wiring untouched — this is template/presentation only.
22. **Sticky channel switcher on mobile**: a horizontally scrollable chip row
    (`1 Left`, `2 Right`, …, styled like the EQ band chips) that sticks under the
    tab bar (`sticky top-0`) on `< lg`, scrolls to + expands the tapped channel.
23. Grid stays `grid-cols-1 lg:grid-cols-2 2xl:grid-cols-4`; with collapsed-by-default
    strips the height mismatch problem mostly disappears. Use `self-start` /
    `items-start` so expanding one card doesn't stretch its row-mates.

## Phase 6 — Verification & polish pass

24. Run `npm run test` and `npm run test:contract`.
25. Add/update unit tests for `formatValue` in `tests/unit/utilities.test.js`.
26. Manual visual sweep against the mock server at 375px and 1280px:
    Home, editor Tuning + Channels, Analyzer, Tools; modal open on a scrolled
    Channels page (regression check for #14); Dim pill; keyboard: Escape closes
    modal, sliders operable, value-edit commit/cancel.
27. Do not flash the device (`pio ... -t uploadfs`). Building is harmless:
    `ESP/esp-web-server/data/dist` is just a symlink to `WebUI/dist` and
    nothing reaches the device until a flash.

## Out of scope

- Anything under `ESP/`, `Teensy/`, `mock-server/` (except reading).
- `api-client.js` request/response shapes.
- New dependencies (no component libraries, no focus-trap packages).
- The deferred items listed at the top.

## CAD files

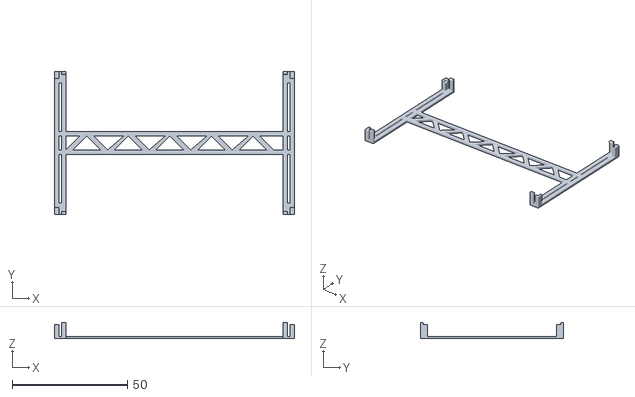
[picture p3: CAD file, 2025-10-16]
3d/Vybes Chassis.stl
104.0 x 62.0 x 7.00

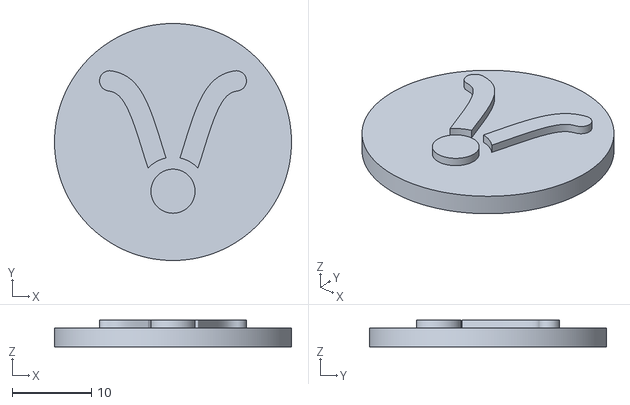
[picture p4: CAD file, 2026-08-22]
docs/brand/vybes-coin.stl
30.0 x 30.0 x 3.40

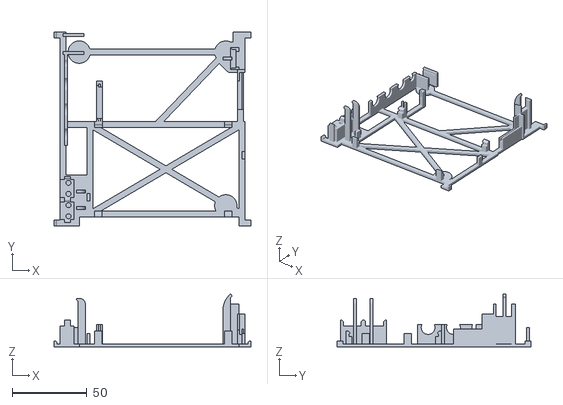
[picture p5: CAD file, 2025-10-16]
3d/Vybes Core.stl
132.0 x 130.0 x 35.4

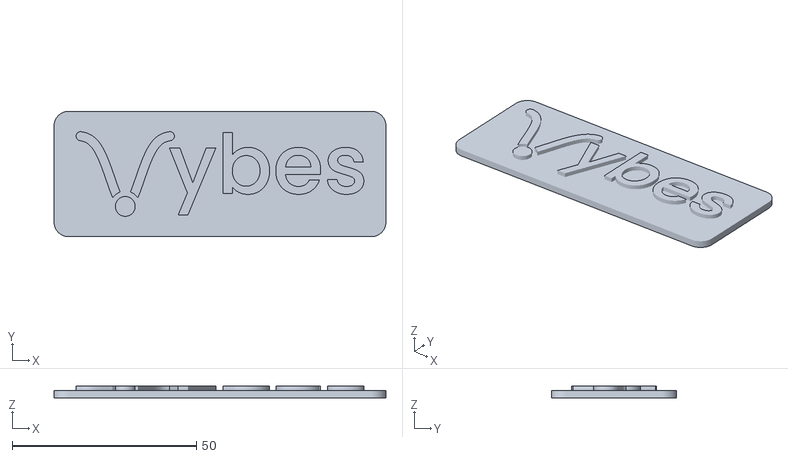
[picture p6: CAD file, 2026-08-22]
docs/brand/vybes-badge.stl
90.0 x 34.0 x 3.20

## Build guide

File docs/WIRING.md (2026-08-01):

# Vybes wiring

Full connection reference for everything the firmware touches. The ESP32 and
Teensy talk over a **UART serial link** (115200 baud, 3.3V logic); I2C on the
ESP is used only for the 1602 LCD backpack.

```
              WIFI / web UI                            audio in: SPDIF, I2S (BT), USB, analog
                   │                                   audio out: octal I2S DACs, SPDIF
             ┌─────┴──────┐      UART 115200       ┌─────────────┐
  LCD, IR,   │   ESP32    │  GPIO17 ──────→ pin 0  │  Teensy 4.1 │── SD card
  button ────│  DevKitC   │  GPIO16 ←────── pin 1  │             │   (built-in slot)
             └────────────┘                        └─────────────┘
```

A full visual diagram (ESP32-S3 pin numbers) lives in
[wiring-diagram.svg](wiring-diagram.svg).

## ESP32 pins

Two boards are supported; pin maps live in `ESP/esp-web-server/board_pins.h`
and the build env picks the right one (`pio run -d ESP` for the classic
DevKitC, `-e esp32s3` for the S3 — see `ESP/platformio.ini`).

| Signal | ESP32 DevKitC (WROOM-32) | ESP32-S3 DevKitC-1 | Purpose |
|---|---|---|---|
| TX2 → Teensy **pin 0** (RX1) | GPIO **17** | GPIO **17** | ESP → Teensy commands (UART2, 115200) |
| RX2 ← Teensy **pin 1** (TX1) | GPIO **16** | GPIO **16** | Teensy → ESP replies/events |
| LCD backpack SCL | GPIO **22** | GPIO **9** | I2C clock — 1602 LCD via PCF8574 @ 0x27 |
| LCD backpack SDA | GPIO **21** | GPIO **8** | I2C data |
| IR receiver data out | GPIO **4** | GPIO **4** | IR remote input (`remote_control.cpp`) |
| Front button (other leg to GND) | GPIO **32** | GPIO **5** | Preset cycling / pairing (internal pull-up) |
| Bluetooth module pairing input  | GPIO **33** | GPIO **6** | Driven HIGH while the button is held (`button.cpp`) |
| Debug console + flashing | USB port | USB port labeled "UART" | 115200 baud |
| Common ground | GND | GND | Shared with Teensy, DACs, BT module |

No external pull-up resistors are needed on the I2C lines — the PCF8574
backpack has its own on-board.

When rewiring onto other pins, avoid:

- **Classic ESP32**: GPIO 0, 2, 5, 12, 15 (boot strapping) and 34-39
  (input-only, no internal pull-ups)
- **ESP32-S3**: GPIO 0, 3, 45, 46 (strapping), 19/20 (native USB),
  26-32 (SPI flash) and 33-37 (used by octal-PSRAM modules)

## Teensy 4.1 pins

These pins are fixed by the Audio library objects used in
`Teensy/fir_filters/fir_filters.ino` — they are not configurable.

### Outputs

Analog output is octal I2S (`AudioOutputI2SOct`): up to four stereo DAC
boards on four data lines, all sharing the I2S1 clocks. Every DAC board
wires its BCK to pin 21 and LCK to pin 20; only DIN differs per board.

| Teensy pin | Signal | Connects to | Purpose |
|---|---|---|---|
| **7** | OUT1A (data)  | DAC board 1 (PCM5102A) DIN | Channels 1-2: main L & R |
| **32** | OUT1B (data)  | DAC board 2 (PCM5102A) DIN | Channels 3-4: subwoofer, mirrored to both outputs (two subs supported) |
| **6** | OUT1C (data)  | DAC board 3 DIN (future) | Channels 5-6: unused |
| **9** | OUT1D (data)  | DAC board 4 DIN (future) | Channels 7-8: unused |
| **21** | BCLK1 | All DAC boards BCK | I2S1 bit clock (shared with BT input) |
| **20** | LRCLK1 | All DAC boards LCK | I2S1 word clock (shared with BT input) |
| **14** | SPDIF OUT | Toslink transmitter | `AudioOutputSPDIF3` pass-through |

The subwoofer signal is mirrored to both outputs of DAC board 2 (same as
the old `AudioOutputI2S2` wiring), so one or two subs can be connected.
Moving all analog outputs onto I2S1 freed the I2S2 port, which now hosts
the analog line-in ADC (see Inputs); its output side (pin 2) is still
unused.

### Inputs

| Teensy pin | Signal | Connects to | Purpose |
|---|---|---|---|
| **15** | SPDIF IN | Toslink receiver | `AsyncAudioInputSPDIF3` optical input |
| **8** | IN1 (data) | Bluetooth receiver I2S out| `AudioInputI2S` — BT audio |
| **5** | IN2 (data) | ADC (PCM1808) DOUT | `AudioInputI2S2` — analog line-in |
| **4** | BCLK2 | ADC BCK | I2S2 bit clock |
| **3** | LRCLK2 | ADC LRC | I2S2 word clock |
| **33** | MCLK2 | ADC SCK/SCKI | I2S2 master clock (the PCM1808 needs it) |
| USB port | — | Source device | `AudioInputUSB` (USB sound card) |

The Bluetooth input shares the I2S1 clocks (BCLK1 = 21, LRCLK1 = 20) with the
L/R DAC. The Teensy is the I2S clock master on that bus, so the Bluetooth
board must be wired to those same clock lines and run as an I2S slave.

### Bluetooth module (TinySine AudioB I2S v3)

Product page: <https://www.tinysineaudio.com/products/audiob-i2s-v3-bluetooth-digital-audio-receiver-module-i2s-slave>

| AudioB pin | Signal | Connects to | Notes |
|---|---|---|---|
| **8** | BCK | Teensy pin 21 (BCLK1) | shared I2S1 bit clock |
| **9** | SD | Teensy pin 8 (IN1 data) | audio data out |
| **10** | LRCK | Teensy pin 20 (LRCLK1) | shared I2S1 word clock |
| **11** | VIN | 5V | |
| **16** | GND | common ground | |
| **15** | +1.8V out  | control-pin pull source | for the module's own buttons |
| **17-20**  | FORWARD / REWIND / PLAY-PAUSE / MUTE | control inputs | **1.8V logic** — always through 8.2kΩ series resistors |

Watch-outs:

- The control pins (17-20) are **1.8V logic**: the module's own button wiring
  pulls them to the +1.8V pin (15) through 8.2kΩ. The ESP's pairing output
  (GPIO33 classic / GPIO6 S3) drives the pairing control input in place of a
  button press — keep the 8.2kΩ series resistor in that line so the 3.3V GPIO
  can't overdrive the pin. Wire it to whichever control input triggers pairing
  on your module's firmware (see the TinySine manual).
- The header pitch is **2.0mm, not 2.54mm** — it won't fit a breadboard or
  0.1" perfboard. Solder wires directly to the pins or use a 2.0mm→2.54mm
  adapter PCB.

The analog line-in ADC lives on I2S2, where the Teensy is also clock master.
A PCM1808 breakout works as-is: it defaults to I2S slave format and takes
its system clock from MCLK2 (pin 33, 256×fs). Wire VCC (3.3V), GND, and the
four signals per the table; line-level sources connect straight to the
board's L/R inputs.

### Other

| Connection | Purpose |
|---|---|
| Built-in SD slot| FIR filter files (`SD.begin(BUILTIN_SDCARD)`) |
| Pins **0 / 1**  | Serial1 link to the ESP32 (see above) |
| USB port | Debug serial console + USB audio (built with `USB_MIDI_AUDIO_SERIAL`) |

### PCM5102A DAC boards

All DAC boards are PCM5102A modules: wire VIN (3.3V), GND, BCK, LCK and DIN
per the tables above. BCK and LCK are daisy-chained across every board;
each board gets its own DIN line. The Teensy does not supply a master
clock — leave the module's SCK tied to GND (most boards do this on-board)
so the DAC generates its own. Keep the shared clock runs short; a 100 Ω
series resistor at the Teensy end of BCK and LCK is cheap insurance
against ringing once several boards hang off them.

The DAC boards are powered from a dedicated **5V → 3.3V linear regulator**
(kept off the ESP/Teensy 3.3V rails for a quieter supply), with a **100nF
ceramic capacitor across each board's VIN-GND**, close to the pins.

## Front button & Bluetooth pairing

The button (GPIO32 → GND) is polled with an internal pull-up:

- **Short press**: wakes the LCD backlight; further presses cycle presets.
  The selected preset is applied ~1s after the last press.
- **Hold > 0.5s**: GPIO33 goes HIGH (Bluetooth pairing line) and the screen
  prompts "Hold for 3s to pair"; after ~3.6s it shows "Pairing mode...".
  GPIO33 returns LOW on release.

## Debug console

The ESP32 has enough UARTs that the Teensy link lives on UART2, so debug
output is simply on the **USB port at 115200 baud**
(`pio device monitor -b 115200`). The Teensy's debug output is on its own
USB serial port.

## HTTPS certificates

The web server also listens on HTTPS (port 443) when a certificate exists on
LittleFS at `/certs/server.crt` + `/certs/server.key`. Generate one with
`ESP/make-certs.sh` (mkcert) and upload it with `pio run -d ESP -t uploadfs`;
without certs the device serves plain HTTP only. HTTPS is what lets browsers
grant microphone access to the analyzer page — trust the mkcert root CA on
each phone/laptop that should use the mic (steps in the script header).

## Boot notes

- On boot the Teensy sends `EVENT boot`, and the ESP responds by pushing the
  full DSP state (preset parameters, EQ, gains, FIR files). The ESP also
  pings every 5s as a fallback, so either device can restart independently
  and the system converges.

## Protocol (for reference)

Newline-delimited text, same command vocabulary as before:

- ESP → Teensy: `setEq 3 1000.0 1.00 -3.0`, `setVolume 0.45`, `ping`, ...
- Teensy → ESP: `PONG <uptime-ms>`, `EVENT boot`, and for `getFiles`:
  a `FILES` line, one filename per line, then `EOT`.

## FIR engine and latency compensation

The FIR filters run through a fast convolution engine (uniformly partitioned
overlap-save: the filter is split into 128-tap partitions convolved in the
frequency domain), which supports filters up to 4096 taps per channel using
a few percent of the CPU. `FIR_USE_FAST_CONVOLUTION` in
`Teensy/fir_filters/fir_filters.ino` switches back to the original
direct-form engine (max 2048 taps, CPU-bound); both engines produce
identical, sample-aligned output.

The Teensy automatically pads the delay lines so channels with different
FIR tap counts stay time-aligned (a linear-phase FIR delays its channel by
(taps−1)/2 samples ≈ 23ms at 2048 taps, ≈ 46ms at 4096). If your existing
speaker-delay settings were manually tuned to absorb FIR latency, re-check
them after this update. If you use minimum-phase FIR files (which have no
inherent latency), this compensation will overshoot — say so and it can be
made configurable.

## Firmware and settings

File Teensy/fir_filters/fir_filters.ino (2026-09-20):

#include <Audio.h>
#include <SPI.h>
#include <SD.h>
#include <SerialFlash.h>
#include <malloc.h>
#include "FIRLoader.h"
#include "PEQProcessor.h"
#include "HeadroomMath.h"
#include "DynamicEqMath.h"
#include "CrossoverFilter.h"
#include "MultibandCompressor.h"
#include "SerialCommandRouter.h"
#include "TeensyCommands.h"
#include "teensy_protocol.h" // FIR_PUT_* - espRxBuffer is sized against these
#include "OutputStream.h"
#include "AudioFilterFIRFloat.h"
#include "IntervalTimer.h"
#include "RtaFFT4096.h"
#include "ProbeSource.h"
#include "AsyncAudioInputUSB.h"
#include "SdRecorder.h"
#include "SdWavPlayer.h"
#include "PeakMeter.h"
#include "SketchState.h" // OutputState/State + the sketch's exported surface
#include "AudioHold.h"
#include "FirFiles.h"
#include "TelemetryStreams.h"
#include "DelayProbe.h"
#include "RecorderControl.h"

// V1 8-output architecture (docs/CHANNEL_ARCHITECTURE.md): a shared stereo
// input stage (source mixing + input EQ) feeds eight identical output
// channels, each with its own source mix, HP/LP crossover, 10-band PEQ, FIR
// filter, delay and gain/invert/mute amp. The Teensy is dumb and
// per-channel: the ESP resolves crossover references and templates to
// concrete per-channel values before sending.

// Command link to the ESP: Serial1 = pins 0 (RX1) and 1 (TX1).
// See docs/WIRING.md in the repo root.
#define ESP_LINK_BAUD 115200
SerialCommandRouter router(Serial1);

// Duration of the smooth morph applied to EQ changes (ms)
#define EQ_MORPH_MS 50

// Maximum per-channel delay in microseconds. AudioEffectDelay holds the
// delayed audio in the AudioMemory pool, so an unbounded delay would
// exhaust it and kill all audio.
#define MAX_DELAY_US 20000

// FIR engine: 1 = fast convolution (FFT-based uniformly partitioned
// overlap-save; long filters at a fraction of the CPU), 0 = the original
// direct-form CMSIS FIR. Both engines produce identical, block-aligned output.
#define FIR_USE_FAST_CONVOLUTION 1

// Audio block pool size (see the AudioMemory call in setup for the budget).
// The FIR tap pool and its static arena live in FirFiles.{h,cpp}.
#define AUDIO_POOL_BLOCKS (FIR_USE_FAST_CONVOLUTION ? 480 : 240)

// RAM2 heap and audio-block-pool stats, printed where the budget matters.
// "unclaimed" is heap sbrk has never handed out; "reclaimable" is what
// mallinfo reports free inside the claimed region. Treat the sum as a floor,
// not the free heap: both numbers held still across a 196,608-byte FIR load
// (2026-08-22), so malloc's top chunk is not in either of them. The linker's
// "free for malloc/new" is the number to size anything against.
extern unsigned long _heap_end;
extern char* __brkval;
void printMemoryStats(const char* tag) {
  struct mallinfo mi = mallinfo();
  Serial.printf("MEM %s: heap unclaimed %lu + reclaimable %lu bytes, audio blocks %d used (max %d of %d)\n",
                tag, (unsigned long)((char*)&_heap_end - __brkval),
                (unsigned long)mi.fordblks,
                AudioMemoryUsage(), AudioMemoryUsageMax(), AUDIO_POOL_BLOCKS);
}

// Audio generators
AudioSynthWaveform       Tone_generator;
AudioSynthNoisePink      pink1;
ProbeSource              probeSource; // auto delay alignment chirps

// USB input engine: 1 = AsyncAudioInputUSB (ring buffer + resampler, immune
// to host clock drift and packet burst jitter; needs the core_fork packet
// hook), 0 = the stock AudioInputUSB running on the core_fork's deepened
// receive queue. Both are stereo with identical patchcords.
//
// 0 is the default: the resampler costs ~88KB of heap (71KB filter tables +
// 16KB ring) and ~9-10ms of input latency, and the deep queue at a target of
// 1 block reaches ~4.4ms without it. The async path stays maintained (native
// tests test_usb_rx_ring / test_usb_resampler) for the case the stock path
// cannot handle: a host that ignores the isochronous feedback endpoint and
// so free-runs against our clock. Watch the 20s underrun/overrun print - a
// climbing count is the signal to set this back to 1.
#define USB_INPUT_ASYNC 0

//Audio Inputs (Bluetooth, SPDIF, USB, analog)
AudioInputI2S            Bluetooth_in;
AsyncAudioInputSPDIF3    Optical_in;
#if USB_INPUT_ASYNC
AsyncAudioInputUSB       USB_in;
#else
AudioInputUSB            USB_in;
#endif
// Stereo ADC (e.g. PCM1808) on I2S2: data pin 5, BCLK pin 4, LRCLK pin 3,
// MCLK pin 33. The Teensy is clock master; the ADC runs as a slave.
AudioInputI2S2           Analog_in;

// Input mixers. Left/Right_mixer channels: 0=optical, 1=bluetooth, 2=USB,
// 3=aux stage. The aux mixers carry the generator and analog inputs (the
// main mixers have no channels left), so their gains are applied there and
// main channel 3 stays at 1.0.
AudioMixer4              Left_mixer;
AudioMixer4              Right_mixer;
AudioMixer4              Left_Aux_mixer;
AudioMixer4              Right_Aux_mixer;
AudioMixer4              Generator_mixer;

// Shared input EQ (the L/R buses ahead of the per-output routing matrix).
// The pre-EQ amps attenuate to compensate for the EQ curve's maximum boost
// (less the spectral allowance - see HeadroomMath.h).
AudioAmplifier           Left_Pre_EQ_amp;
AudioAmplifier           Right_Pre_EQ_amp;
PEQProcessor peqLeft;
PEQProcessor peqRight;

// Mixed-input multiband compressor: sits after the input EQ, ahead of the
// per-output source mixers, so every output hears the same dynamics.
MultibandCompressor inputComp;

// Per-output processing chain, one entry per output channel 0-7:
// source mixer (in 0 = L bus, in 1 = R bus) -> HP/LP crossover -> PEQ ->
// FIR -> delay -> amp (gain * volume, invert via negative gain, mute via 0).
// Bypass lives inside the objects (crossover/PEQ/FIR pass through when idle,
// delay time 0 is a passthrough) - no patchcord swapping.
AudioMixer4              sourceMixer[NUM_OUTPUTS];
CrossoverFilter          xover[NUM_OUTPUTS];
PEQProcessor             outputPeq[NUM_OUTPUTS];
AudioFilterFIRFloat      firFilter[NUM_OUTPUTS];
AudioEffectDelay         outputDelay[NUM_OUTPUTS];
AudioAmplifier           outputAmp[NUM_OUTPUTS];

// Outputs
// Analog output is octal I2S: four data lines (pins 7, 32, 6, 9) sharing the
// I2S1 clocks (BCLK=21, LRCLK=20), each feeding a stereo PCM5102A board.
// Output channels 0-7 map 1:1 onto the octal I2S channels; SPDIF mirrors
// outputs 0 and 1.
AudioOutputSPDIF3        L_R_Spdif_Out;
AudioOutputI2SOct        Analog_Out;

// RTA spectrum tap: a 4096-point FFT whose 1/12-octave band levels stream to
// the web UI over the ESP link. Its input is switched by updateRtaSource():
// the L+R source mix (pre-DSP) for the input scope, or a single soloed
// output's post-crossover signal so the "source" trace is band-limited
// exactly like that driver (a soloed sub then shows no energy above its
// low-pass, and the analyzer's mic/source comparison lines up instead of
// trying to correct bands the driver can't reproduce). The FFT input is
// disconnected while idle so it costs no CPU (see rtaLoop).
AudioMixer4              RTA_mixer;
RtaFFT4096               RTA_fft;

// SD recorder taps (the full mixed stereo input, pre input-EQ, so recordings
// are independent of preset EQ and master volume) and the SD WAV player,
// which feeds the aux mixers' input 2 and so plays through the whole input
// chain like any other source. Mutual exclusion (never record and play at
// once) is enforced in the handlers; both only ever touch the card from
// loop() context.
AudioRecordQueue         recordQueueL;
AudioRecordQueue         recordQueueR;
SdWavPlayer              sdPlayer;

// Stereo peak/clip meter on the input bus (drives the web UI's level bars
// via "VU" frames; see vuLoop)
PeakMeter                inputMeter;

// Connections (input stage - fixed, so wired at construction)

// Generator connections
AudioConnection          patchCord_GenToneToMixer(Tone_generator, 0, Generator_mixer, 0);
AudioConnection          patchCord_PinkToMixer(pink1, 0, Generator_mixer, 1);
AudioConnection          patchCord_ProbeToGenMixer(probeSource, 0, Generator_mixer, 2);
AudioConnection          patchCord_GenMixerToLeftAux(Generator_mixer, 0, Left_Aux_mixer, 0);
AudioConnection          patchCord_GenMixerToRightAux(Generator_mixer, 0, Right_Aux_mixer, 0);

// External input connections
AudioConnection          patchCord_OpticalLToLeftMixer(Optical_in, 0, Left_mixer, 0);
AudioConnection          patchCord_OpticalRToRightMixer(Optical_in, 1, Right_mixer, 0);
AudioConnection          patchCord_BluetoothLToLeftMixer(Bluetooth_in, 0, Left_mixer, 1);
AudioConnection          patchCord_BluetoothRToRightMixer(Bluetooth_in, 1, Right_mixer, 1);
AudioConnection          patchCord_USBLToLeftMixer(USB_in, 0, Left_mixer, 2);
AudioConnection          patchCord_USBRToRightMixer(USB_in, 1, Right_mixer, 2);
AudioConnection          patchCord_AnalogLToLeftAux(Analog_in, 0, Left_Aux_mixer, 1);
AudioConnection          patchCord_AnalogRToRightAux(Analog_in, 1, Right_Aux_mixer, 1);
AudioConnection          patchCord_LeftAuxToLeftMixer(Left_Aux_mixer, 0, Left_mixer, 3);
AudioConnection          patchCord_RightAuxToRightMixer(Right_Aux_mixer, 0, Right_mixer, 3);

// RTA tap connections (the FFT link starts disconnected; see setup).
// updateRtaSource() feeds RTA_fft from exactly one of these at a time:
// patchCord_RTAMixerToFFT for the input scope, patchCord_SoloToFFT (rebound
// to the soloed output's crossover) while an output is soloed.
AudioConnection          patchCord_LeftMixerToRTA(Left_mixer, 0, RTA_mixer, 0);
AudioConnection          patchCord_RightMixerToRTA(Right_mixer, 0, RTA_mixer, 1);
AudioConnection          patchCord_RTAMixerToFFT(RTA_mixer, 0, RTA_fft, 0);
AudioConnection          patchCord_SoloToFFT; // bound to xover[solo] on demand

// Recorder tap and player injection points
AudioConnection          patchCord_LeftMixerToRec(Left_mixer, 0, recordQueueL, 0);
AudioConnection          patchCord_RightMixerToRec(Right_mixer, 0, recordQueueR, 0);
AudioConnection          patchCord_PlayerToLeftAux(sdPlayer, 0, Left_Aux_mixer, 2);
AudioConnection          patchCord_PlayerToRightAux(sdPlayer, 1, Right_Aux_mixer, 2);

// Input bus meter taps
AudioConnection          patchCord_LeftMixerToMeter(Left_mixer, 0, inputMeter, 0);
AudioConnection          patchCord_RightMixerToMeter(Right_mixer, 0, inputMeter, 1);

SdRecorder               sdRecorder(recordQueueL, recordQueueR);

// Input EQ patchcords
AudioConnection patchCord_LeftMixerToPreEQ(Left_mixer, 0, Left_Pre_EQ_amp, 0);
AudioConnection patchCord_RightMixerToPreEQ(Right_mixer, 0, Right_Pre_EQ_amp, 0);
AudioConnection patchCord_LeftPreEQToPEQ(Left_Pre_EQ_amp, 0, peqLeft, 0);
AudioConnection patchCord_RightPreEQToPEQ(Right_Pre_EQ_amp, 0, peqRight, 0);
AudioConnection patchCord_LeftPeqToComp(peqLeft, 0, inputComp, 0);
AudioConnection patchCord_RightPeqToComp(peqRight, 0, inputComp, 1);

// Per-output connections, wired in setup() so they can be built in a loop
// (Teensyduino 1.54+ supports unconnected AudioConnection + connect()).
AudioConnection busCords[NUM_OUTPUTS][2];   // L/R bus -> source mixer
AudioConnection chainCords[NUM_OUTPUTS][5]; // mixer->xover->peq->fir->delay->amp
AudioConnection outCords[NUM_OUTPUTS];      // amp -> octal I2S
AudioConnection spdifCords[2];              // outputs 0/1 -> SPDIF

bool sdCardInitialized = false;
bool firFilesPending = false;

// Set by the recorder/player command handlers so recorderStatusLoop() sends
// a fresh "REC STATE" line on its next pass instead of waiting for the 1Hz
// change poll.
bool recStateDirty = false;

// Last time the recorder or player had a file open (refreshed every loop
// pass while one does, and after a delete's FAT write). sdReady() holds off
// media-presence probes for a window past this - see the comment there.
unsigned long sdLastStreamActivityMs = 0;

// --- audio hold ---
// Outputs are silent while any hold source is asserted (boot, nested config
// syncs, a queued FIR load). The state machine, its fail-safe, and the
// rationale live in AudioHold.h.
AudioHold audioHold;

// The preset/DSP state (struct definitions in SketchState.h, which also
// externs this for FirFiles.cpp)
State state;

// --- Output solo (per-output EQ measurement) ---
// Keepalive-driven like the RTA: the ESP refreshes "soloOutput <ch>" every
// couple of seconds while the analyzer measures one output, so a dropped
// connection can't leave the system stuck on one speaker. Rides the amp
// ramp via outputTargetGain (click-free) and changes nothing in the preset
// state; the soloed output keeps its normal gain/volume/mute product.
#define OUTPUT_SOLO_KEEPALIVE_TIMEOUT_MS 7000
int outputSolo = -1;
unsigned long outputSoloLastKeepaliveAt = 0;

// --- Shared output headroom pad ---
// The per-output chains have no per-channel compensation stage (a per-output
// pad would skew the balance between drivers and wreck crossover summing),
// so one shared pad - the largest net output-EQ boost across all channels -
// is folded into every source mixer's gains. "Net" folds in each channel's
// crossover response and the spectral allowance (HeadroomMath.h), so a
// boost the crossover removes, or one riding above 2kHz where program
// energy is sparse, doesn't cost the whole system headroom. Recomputed once
// per loop() pass when
// marked dirty, so a burst of EQ edits (the boot sync) costs one 8-channel
// curve sweep, not eighty.
float outputPadLin = 1.0f;
bool outputPadDirty = false;
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
void loop() {
#if USB_INPUT_ASYNC
  // Rebuild the USB resampler here (not in the audio interrupt) if its
  // kill switch tripped; no-op otherwise. Prints a diagnostic when it runs.
  USB_in.healPending();
  USB_in.diagLoop();
#endif

  // Optional: Print some diagnostics every 20 seconds
  static unsigned long lastPrint = 0;

  if (millis() - lastPrint > 20000) {
    lastPrint = millis();
    Serial.print("Audio Processor Usage: ");
    Serial.print(AudioProcessorUsage());
    Serial.print("% (Max: ");
    Serial.print(AudioProcessorUsageMax());
    Serial.println("%)");
    AudioProcessorUsageMaxReset();
    printMemoryStats("periodic");

#if USB_INPUT_ASYNC
    Serial.print("USB in (async): ");
    Serial.print(USB_in.streaming() ? "streaming" : "idle");
    Serial.print(", buffered ");
    Serial.print(USB_in.bufferedMs(), 1);
    Serial.print(" ms, step ");
    Serial.print(USB_in.stepPpm(), 1);
    Serial.print(" ppm, drops ");
    Serial.print(USB_in.drops());
    Serial.print(", starves ");
    Serial.print(USB_in.starves());
    Serial.print(", stops ");
    Serial.print(USB_in.stops());
    Serial.print(", recoveries ");
    Serial.print(USB_in.recoveries());
    Serial.print(", resyncs ");
    Serial.print(USB_in.resyncs());
    Serial.print(", allocfails ");
    Serial.print(USB_in.allocFails());
    // Races the stop detector survived (see UsbRxRing::consumerReady) and the
    // worst host packet gap this interval - 1000us is nominal, a large value
    // means the host really did stall.
    Serial.print(", falsestops ");
    Serial.print(USB_in.falseStops());
    Serial.print(", maxgap ");
    Serial.print(USB_in.takeMaxGapUs());
    Serial.println(" us");
#else
    static uint32_t lastUnderruns = 0, lastOverruns = 0;
    uint32_t underruns = usb_audio_underrun_count;
    uint32_t overruns = usb_audio_overrun_count;
    float usbHz = feedback_accumulator * (1000.0f / 16777216.0f);
    Serial.print("USB in: feedback ");
    Serial.print(usbHz, 2);
    Serial.print(" Hz (");
    Serial.print((usbHz - AUDIO_SAMPLE_RATE_EXACT) * (1e6f / AUDIO_SAMPLE_RATE_EXACT), 1);
    Serial.print(" ppm), queue ");
    Serial.print(usb_audio_rx_queue_count);
    Serial.print(" blocks, underruns +");
    Serial.print(underruns - lastUnderruns);
    Serial.print(" (total ");
    Serial.print(underruns);
    Serial.print("), overruns +");
    Serial.print(overruns - lastOverruns);
    Serial.print(" (total ");
    Serial.print(overruns);
    Serial.println(")");
    lastUnderruns = underruns;
    lastOverruns = overruns;
#endif
  }

  if (firFilesPending) {
    // A FIR load blocks loop() on SD reads and changes channel latencies -
    // either would corrupt a running measurement, so abort the probe first.
    if (probeIsActive()) {
      probeCleanup("PROBE ERR aborted firLoad\n");
    }
    loadFirFiles();
    firFilesPending = false;
    audioHold.setFirLoadHold(false);
  }

  // Fail-safe release: never let a missing or lost setConfigHold 0 leave the
  // device permanently silent (e.g. an ESP on firmware that predates the
  // command). See AudioHold::pollFailsafe.
  if (audioHold.pollFailsafe(router.dispatched(), millis())) {
    Serial.println("WARN: no config sync, releasing audio hold");
  }

  static unsigned long lastMemoryCheck = 0;
  if (millis() - lastMemoryCheck > 60000) {
    lastMemoryCheck = millis();

    Serial.print("Audio Memory Usage: ");
    Serial.println(AudioMemoryUsage());
  }
  router.loop();
  updateAudioVolume(); // Call this frequently to smooth gain changes
  rtaLoop();
  grmLoop();
  vuLoop();
  probeLoop();
  outputSoloLoop();
  outputPadLoop();
  sdRecorder.service();
  sdPlayer.service();
  recorderStatusLoop();
}

// Clear a stale output solo once the ESP's keepalives stop arriving.
void outputSoloLoop() {
  if (outputSolo < 0) return;
  if (millis() - outputSoloLastKeepaliveAt > OUTPUT_SOLO_KEEPALIVE_TIMEOUT_MS) {
    outputSolo = -1;
    updateRtaSource(); // fall back to the L+R mix if RTA is still streaming
    Serial.println("Output solo timed out");
  }
}

// Route the FFT input to match the analyzer scope. Exactly one source feeds
// RTA_fft at a time (its input port holds one connection), so both candidate
// cords are torn down first. Call this whenever rtaStreaming() or outputSolo
// changes - not on every solo keepalive, since re-binding the cord restarts
// the FFT's accumulation window.
void updateRtaSource() {
  patchCord_RTAMixerToFFT.disconnect();
  patchCord_SoloToFFT.disconnect();
  if (!rtaStreaming()) return; // idle: leave the FFT unfed
  if (outputSolo >= 0 && outputSolo < NUM_OUTPUTS) {
    // Post-crossover, pre-PEQ - the same "pre-EQ source" semantics the input
    // scope has (it taps the source mix ahead of the input EQ), so measuring
    // with the output EQ bypassed yields the raw driver+room response.
    patchCord_SoloToFFT.connect(xover[outputSolo], 0, RTA_fft, 0);
  } else {
    patchCord_RTAMixerToFFT.connect();
  }
}

// Move 'current' toward 'target' with an exponential ramp whose speed is
// independent of how fast loop() runs. Returns true if the value changed.
static bool slewToward(float& current, float target, float alpha) {
  const float MIN_CHANGE = 0.001f;
  if (fabsf(target - current) > MIN_CHANGE) {
    current += (target - current) * alpha;
    return true;
  }
  if (current != target) {
    current = target;
    return true;
  }
  return false;
}

// The gain an output's amp should settle at: output gain (dB) * master
// volume, negated for invert, zero when muted. Smoothing rides the whole
// product, so volume, gain, mute and invert changes are all click-free.
// While a delay probe runs, the soloed output gets the probe level times
// its own trim (see the probe state block above) and every other output is
// silenced; normal targets return through the same ramp when it ends.
static float outputTargetGain(int ch, const OutputState& o) {
  // A config sync applies hundreds of commands one at a time, so until it
  // finishes every unsent value is still a boot default - master volume
  // 50%, output gain 0dB, input gains 1.0, crossovers bypassed. Opening an
  // output before its own commands land plays that default state, which is
  // both louder than intended and full-range. Hold every output at zero
  // until the whole picture is in place; updateAudioVolume's ramp makes the
  // release click-free.
  if (audioHold.held()) return 0.0f;
  if (probeIsActive()) {
    // The probe level stands in for master volume and mute (neither may
    // silence a measurement) but NOT for the output's own trim: sweeping a
    // -6dB sub at the full probe level drives it harder than anything it
    // sees in use, which is how the auto-FIR sweep made the sub distort.
    // Safe for the result: the designer re-centers every output's curve on
    // its own in-band median and reads arrival time from the correlation
    // peak, so the trim moves only the measured level and its SNR (which
    // the wizard already reports per output), never the designed kernel.
    // Clamped because gainDb reaches +10dB.
    float gain = probeGainForOutput(ch) * powf(10.0f, o.gainDb / 20.0f);
    if (gain > 1.0f) gain = 1.0f;
    return o.invert ? -gain : gain;
  }
  // Per-output EQ measurement: everything but the soloed output is silenced;
  // the soloed one keeps its normal product so the mic measures reality.
  if (outputSolo >= 0 && ch != outputSolo) return 0.0f;
  if (o.mute) return 0.0f;
  float gain = powf(10.0f, o.gainDb / 20.0f) * state.targetVolume;
  return o.invert ? -gain : gain;
}

// Function to smoothly update the per-output amp gains
void updateAudioVolume() {
  // Time constant of the ramp: ~63% of the way in RAMP_TAU_MS, settled in
  // roughly 3x that. Time-based so SD reads etc. don't change the ramp speed.
  const float RAMP_TAU_MS = 60.0f;

  static unsigned long lastUpdate = 0;
  unsigned long now = millis();
  float dt = (float)(now - lastUpdate);
  lastUpdate = now;
  if (dt <= 0) return;
  float alpha = dt / RAMP_TAU_MS;
  if (alpha > 1.0f) alpha = 1.0f;

  for (int ch = 0; ch < NUM_OUTPUTS; ch++) {
    OutputState& o = state.outputs[ch];
    if (slewToward(o.currentGain, outputTargetGain(ch, o), alpha)) {
      outputAmp[ch].gain(o.currentGain);
    }
  }
}
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

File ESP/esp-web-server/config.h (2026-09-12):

#ifndef CONFIG_H
#define CONFIG_H

#include <Arduino.h>
#include <ArduinoJson.h>

// --- Constants ---
// V1 is a clean break for the 8-output ESP32-S3 + Teensy hardware
// (docs/CHANNEL_ARCHITECTURE.md); there is no migration path from the old
// 3-channel config. The version field and migrate_config hook exist from
// day one so future schema changes migrate in place instead of silently
// reinterpreting fields.
//
// Version history:
// 1 - Initial 8-output V1 schema
// 2 - Added deviceName (multi-device support; older files default to "vybes")
// 3 - Added per-preset dynamics (mixed-input multiband compressor); absent
//     sections parse to defaults (disabled), so no doc rewrite is needed
// 4 - Master volume moved from global state into each preset, so switching
//     presets restores the level it was last played at. The migration seeds
//     every preset with the old global value.
// 5 - Dynamic EQ (docs/DYNAMIC_EQ.md): the input EQ gained two volume
//     anchors (referenceVolume/loudVolume) and a loudness-compensation flag,
//     and PEQSet.spl stopped being an SPL value and became a role tag. The
//     migration anchors every preset's curve at the volume it plays at, so
//     nothing sounds different until a loud anchor is added.
#define CONFIG_CURRENT_VERSION 5

#define MAX_PRESETS 12
// Long enough for the contract suite's generated "contract-test-…" names
#define PRESET_NAME_MAX_LEN 48

// These must match mock-server/templates.js and the contract suite
#define NUM_OUTPUTS 8
#define MAX_CROSSOVER_POINTS 4
#define MAX_OUTPUT_PEQ 10
#define MAX_PEQ_SETS 3
#define MAX_PEQ_POINTS 15   // input EQ points per anchor set
#define FIR_TAP_POOL 12288  // taps shared across all outputs
#define MAX_DELAY_US 20000
#define OUTPUT_GAIN_MIN_DB -40.0
#define OUTPUT_GAIN_MAX_DB 10.0
#define PRESET_VOLUME_DEFAULT 50

#define OUTPUT_LABEL_MAX_LEN 24
#define XOVER_ID_MAX_LEN 15
#define TEMPLATE_ID_MAX_LEN 15
#define FIR_FILENAME_LEN 63

// Device name: one DNS label ("<name>.local"), also the standalone AP SSID.
// Kept well under both the 63-char DNS label and 32-char SSID limits.
#define DEVICE_NAME_MAX_LEN 24
#define DEVICE_NAME_DEFAULT "vybes"

extern const char* CONFIG_FILE;

// --- Data Structures ---

// Represents a single Parametric EQ point
struct PEQPoint {
    float freq = 1000.0f;
    float gain = 0.0f;
    float q = 1.0f;
};

// Role tags for PEQSet::spl. The field was an "EQ per SPL" idea that was
// never implemented; from config v5 it names which volume anchor a set
// belongs to (docs/DYNAMIC_EQ.md). The JSON key keeps its old name so older
// backups parse without a rewrite.
#define EQ_SET_UNUSED -1
#define EQ_SET_REFERENCE 0
#define EQ_SET_LOUD 1

// One anchor's worth of input-EQ bands. spl == EQ_SET_UNUSED means the slot
// is free.
struct PEQSet {
    int spl = EQ_SET_UNUSED;
    PEQPoint points[MAX_PEQ_POINTS];
    int num_points = 0; // Number of active PEQ points in this set
};

// Shared input EQ (preference curve) applied to the L/R buses ahead of the
// routing matrix.
//
// Dynamic EQ: the curve has two anchors. The reference set (EQ_SET_REFERENCE)
// is what the preset sounds like at referenceVolume; the optional loud set
// (EQ_SET_LOUD) is what it should sound like at loudVolume. Band count,
// frequencies and Qs are shared - only gains differ - and the ESP enforces
// that on every write so the Teensy can interpolate band-for-band. Below the
// reference anchor, `loudness` turns on the ISO 226-derived bass
// compensation, which takes no user configuration at all.
struct InputEq {
    bool enabled = false;
    PEQSet sets[MAX_PEQ_SETS];
    // Volume percent (0-100) the reference curve is tuned at
    int referenceVolume = PRESET_VOLUME_DEFAULT;
    // Volume percent of the loud anchor; 0 = no loud anchor configured
    int loudVolume = 0;
    bool loudness = true;
};

// A named, shared crossover point. Output filters reference it by id so one
// edit moves every filter that uses it. locked points reject writes without
// confirm=true (driver protection); min/max bound the frequency.
struct CrossoverPoint {
    char id[XOVER_ID_MAX_LEN + 1] = "";
    uint16_t freq = 80;
    char type[4] = "LR4"; // LR2 | LR4 | BW2
    bool locked = false;
    uint16_t min = 20;
    uint16_t max = 20000;
};

enum class FilterMode : uint8_t { Off, Xover, Manual };

// One HP or LP section of an output. In Xover mode the frequency and type
// come from the referenced crossover point; the xover id is kept while the
// mode is Off so re-enabling restores the reference. freq/type only apply
// in Manual mode.
struct FilterSection {
    FilterMode mode = FilterMode::Off;
    char xover[XOVER_ID_MAX_LEN + 1] = "";
    double freq = 0.0; // double: echoed verbatim by the API, see Output
    char type[4] = "LR4";
};
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

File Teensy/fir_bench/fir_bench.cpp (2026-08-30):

// Cycle-accurate bench for the fast-convolution FIR engine.
//
// Runs FirEngine on its own (no audio graph) so processFast can be timed with
// DWT_CYCCNT at the real 600 MHz clock, with the partition arrays living in
// the same DMAMEM/OCRAM the firmware puts them in. The point is to separate
// the two candidate costs in the complex multiply-accumulate loop:
//
//   - arithmetic: fixed cycles per complex bin, independent of filter length
//   - memory:     partSpectra + fdl are re-streamed from OCRAM every block,
//                 and at a full pool that working set is 6x the L1 D-cache
//
// A sweep over tap counts separates them. One partition is 2 KB and stays
// cache-resident, so its cycles/bin is the pure arithmetic floor; if the
// figure climbs as the working set grows past 32 KB, the loop is (also)
// memory bound. The -cold variant streams a 64 KB buffer between blocks to
// evict the cache the way the rest of the audio graph would.

#include <Arduino.h>
#include "FirEngine.h"

static constexpr uint16_t TAP_POOL = 12288;
static constexpr size_t ARENA_FLOATS =
    (((size_t)TAP_POOL + FirEngine::BLOCK_SAMPLES - 1) / FirEngine::BLOCK_SAMPLES) *
    FirEngine::FFT_SIZE * 2;

// Same placement as firArena in the firmware.
DMAMEM static float arena[ARENA_FLOATS];
// Bigger than the 32 KB L1 D-cache, so one pass evicts it.
DMAMEM static float evictor[16384];

static FirEngine eng;
static float inBlk[FirEngine::BLOCK_SAMPLES];
static float outBlk[FirEngine::BLOCK_SAMPLES];
static volatile float sink;

// One 128-sample block at 44117.647 Hz, in 600 MHz core cycles.
static constexpr float BLOCK_BUDGET = 600000000.0f * 128.0f / 44117.64706f;

static uint32_t rng = 22222;
static inline float nextRand() {
  rng = rng * 1664525u + 1013904223u;
  return (float)(int32_t)rng * (1.0f / 2147483648.0f);
}

// Decaying noise impulse response - non-trivial spectrum in every partition,
// no denormals, no accidental symmetry.
struct NoiseFeed : CoeffFeed {
  uint32_t n = 0;
  uint16_t total;
  explicit NoiseFeed(uint16_t t) : total(t) {}
  uint16_t read(float* dst, uint16_t count) override {
    for (uint16_t i = 0; i < count; i++) {
      dst[i] = nextRand() * expf(-4.0f * (float)n / (float)total) * 0.05f;
      n++;
    }
    return count;
  }
};

static void evictCache() {
  float s = 0;
  for (size_t i = 0; i < 16384; i += 8) s += evictor[i];
  sink = s;
}

static void runCase(uint16_t taps, bool cold, uint32_t blocks) {
  NoiseFeed feed(taps);
  eng.setFastConvolution(true);
  if (!eng.reservePendingIn(arena, taps) || !eng.fillPending(feed)) {
    Serial.printf("%5u taps: LOAD FAILED\n", taps);
    return;
  }
  eng.swapPending();
  eng.freeRetired();
  eng.resetHistory();

  const uint16_t parts = (taps + FirEngine::BLOCK_SAMPLES - 1) / FirEngine::BLOCK_SAMPLES;

  // Fill the frequency-domain delay line before timing anything.
  for (uint16_t i = 0; i < parts + 4; i++) eng.processBlock(inBlk, outBlk);

  firProfFwd = firProfMac = firProfInv = firProfBlocks = 0;
  uint32_t t0 = ARM_DWT_CYCCNT;
  for (uint32_t b = 0; b < blocks; b++) {
    if (cold) evictCache();
    eng.processBlock(inBlk, outBlk);
  }
  uint32_t wall = ARM_DWT_CYCCNT - t0;
  sink = outBlk[0] + outBlk[64];

  const double n = (double)blocks;
  const double mac = firProfMac / n;
  const double fwd = firProfFwd / n;
  const double inv = firProfInv / n;
  const double fir = mac + fwd + inv;
  // 127 full complex bins per partition; DC and Nyquist are handled separately.
  const double perBin = mac / ((double)parts * 127.0);

  Serial.printf("%5u %4u %s %9.0f %8.0f %8.0f %9.0f %7.2f %8.1f%%  %6.1f%%\n",
                taps, parts, cold ? "cold" : "warm",
                mac, fwd, inv, fir, perBin,
                100.0 * fir / BLOCK_BUDGET,
                100.0 * mac / fir);
  (void)wall;
}

static void report();

void setup() {
  Serial.begin(115200);

  // DWT cycle counter
  ARM_DEMCR |= ARM_DEMCR_TRCENA;
  ARM_DWT_CTRL |= ARM_DWT_CTRL_CYCCNTENA;

  for (int i = 0; i < FirEngine::BLOCK_SAMPLES; i++) inBlk[i] = nextRand() * 0.25f;
  for (size_t i = 0; i < 16384; i++) evictor[i] = 1.0f + (float)i;
}

// Repeated on a timer rather than run once at boot, so the report can be read
// by attaching to the port at any point instead of having to race the reset.
static void report() {
  Serial.println();
  Serial.println("=== Vybes fast-convolution FIR bench ===");
  Serial.printf("F_CPU %lu Hz, block budget %.0f cycles (128 smp @ 44117.6 Hz)\n",
                (unsigned long)F_CPU, BLOCK_BUDGET);
  Serial.printf("arena %u floats (%u KB) in DMAMEM/OCRAM, L1 D-cache 32 KB\n\n",
                (unsigned)ARENA_FLOATS, (unsigned)(ARENA_FLOATS * 4 / 1024));
  Serial.println(" taps part  mem  mac_cyc  fwdfft  invfft  fir_cyc  cyc/bin  %budget  mac%fir");
  Serial.println("------------------------------------------------------------------------------");

  const uint16_t sweep[] = {128, 256, 512, 1024, 2048, 4096, 8192, 12288};
  for (uint16_t t : sweep) runCase(t, false, 2000);
  Serial.println();
  for (uint16_t t : sweep) runCase(t, true, 2000);
  Serial.println("\ndone.");
}

void loop() {
  static uint32_t last = 0;
  if (Serial && (last == 0 || millis() - last > 20000)) {
    last = millis();
    report();
  }
}

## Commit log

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2025-05-24 fix: Update Web UI title and README wiring diagram per feedback
    Addresses your feedback:
    - Changes the Web UI title in App.vue to "Vybes" and removes tech-specific branding.
    - Updates README.md:
    - Removes the previous software component interaction diagram.
    - Adds a new "Hardware Wiring Diagram" section.
    - Provides a detailed textual description of physical pin connections (Power, Serial) between ESP8266 and Teensy.
    - Includes a Mermaid diagram to visually represent these hardware connections.
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2025-05-24 fix: Correct another Mermaid diagram syntax error in README.md
    Moves a second misplaced comment in the Mermaid diagram that was causing a parse error. The comment for "Or 5V, check module for SPDIF Converter" is now on its own line preceding the relevant connection.
2025-05-24 docs: Revert README to simpler system architecture overview
    Removes the detailed "Hardware Wiring Diagram" section (text and complex Mermaid diagram) from README.md as per your request to focus on code rather than detailed, evolving hardware documentation.
    Restores the original "System Architecture" textual description and the simpler, high-level Mermaid diagram showing the interaction between ESP8266, Teensy, and WebUI components.
2025-05-25 feat: Build out Vue 3 application views and functionality
    Implements the core views for the Vybes WebUI as per issue requirements:
    - Home: Displays live system status.
    - Calibration: Allows you to set SPL calibration.
    - Tools: Provides tone/noise generation and test pulse.
    - EQ Control: Integrates the existing ParametricEQ component (though actual preset selection for it is in PresetEditorView).
    - Preset Editor: Enables full CRUD operations for presets and editing their EQ settings using the ParametricEQ component.
    - Data Structures: A viewer for raw preset data from the API.
    Key features:
    - View components created in `src/views`.
    - Navigation implemented in `App.vue` without Vue Router, us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
2025-06-16 Fixed Teensy compilation errors
    [fir_filters.ino]
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2025-06-18 Fix issues with FIR filter
    [fir_filters.ino]
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2025-07-03 Make I2C more reliable, start fixing ESP API
    [api_fir.cpp, button.cpp, config.cpp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]
2025-07-05 Extra logging, fix regex url
    [esp-web-server.ino, web_server.cpp]
2025-07-06 Fix put requests (added "#define ASYNCWEBSERVER_REGEX 1" to ESPAsyncWebServer.h, added condition to WiFiManager.cpp to include AsyncWebServer instead of ESP8266WebServer)
    [esp-web-server.ino]
2025-07-07 Remove libraries folder because it doesn't work
    [config.h, i2c.cpp]
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2025-07-17 Add Input gains, fix enable routes
    [web_server.cpp]
2025-07-17 Fix issue with multiple "Default" presets
    [config.cpp, web_server.cpp]
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2025-07-27 Fix negative crossover issue, make FIR filter inputs text rather than select
    [config.h, fir_filters.ino, web_server.cpp]
2025-08-02 Reduce gain before EQ to avoid distortion
    [fir_filters.ino]
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2025-09-14 Fix volume set error
    [fir_filters.ino]
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2025-10-16 Fix FIR filter loading
    [fir_filters.ino]
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2025-11-14 Make speaker balance slider update automatically Fix flood of commands to Teensy when speaker gains are updated Fix mute functionality Prevent zoom from showing when holding press on slider knob
    [config.cpp, fir_filters.ino]
2025-11-15 Trying to improve reliability and avoid crash
    [config.cpp, teensy_comm.cpp, teensy_comm.h]
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2026-08-09 Upgrade USB audio to prevent glitches
    [AsyncAudioInputUSB.cpp, AsyncAudioInputUSB.h, fir_filters.ino]
2026-08-09 Fix USB audio not working
    [AsyncAudioInputUSB.cpp, AsyncAudioInputUSB.h, fir_filters.ino]
2026-08-09 USB audio update to prevent drops
    [AsyncAudioInputUSB.cpp]
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2026-08-15 Add more monitoring and a health check to try and prevent hanging or restarting
    [esp-web-server.ino, fir_filters.ino, health.cpp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]
2026-08-16 Fix USB audio stream glitches
    [AsyncAudioInputUSB.cpp, AsyncAudioInputUSB.h, fir_filters.ino]
2026-08-16 Fix Teensy build: forward-declare OutputState
    The .ino prototype generator inserts generated prototypes partway down the
    globals, above where struct OutputState is defined further down the sketch.
    outputTargetGain(int, const OutputState&) is therefore declared before the
    type exists and the build fails with "'OutputState' does not name a type".
    A reference parameter only needs the type declared, so forward-declare it
    after the includes - ahead of the generator's insertion point.
    [fir_filters.ino]
2026-08-16 Fix false USB stream stops causing periodic clicks
    AsyncAudioInputUSB's host-stop detector compared timestamps unsigned:
    if (active && (uint32_t)(nowMicros - lastRxMicros) > stopGap)
    nowMicros is sampled by update() in the audio software ISR (priority 208).
    lastRxMicros is stamped by rxHook() in the USB ISR (priority 128, the core
    default), which preempts it. A packet landing between the micros() sample and
    this comparison leaves lastRxMicros legitimately in the future, and the
    unsigned difference wraps to ~4.29e9 - always past the 100ms stop gap.
    Each false stop discarded the whole ring cushion, re-armed the prefill gate
    and forced a resync on resume: ~12ms of silence plus two wavefo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
    [fir_filters.ino]
2026-08-16 Hold audio silent until a config sync has fully applied
    A Teensy reboot under a running ESP briefly played boot defaults - master
    volume 50%, output gain 0dB, input gains 1.0, crossovers bypassed - because
    a sync is ~195 commands applied one at a time and nothing stopped an output
    being audible before its own values arrived. Heard as a loud burst at
    startup, and the same window opens on every preset switch.
    Three changes:
    1. setConfigHold <0|1> brackets a full sync. While held the Teensy pins every
    output amp to zero through outputTargetGain(), so a half-applied config is
    never audible; updateAudioVolume's existing 60ms ramp makes the release
    click-free. The Teensy also holds from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
    [button.cpp, config.cpp, fir_filters.ino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]
2026-08-16 Surface FIR load failures, filter dotfiles, revalidate the SD card
    Three faults found while diagnosing a preset that was silently running with
    no room correction at all.
    1. A failed FIR load was invisible. The Teensy printed "FIR Error: ..." to its
    own USB console and nothing else; the web UI went on showing the channel as
    FIR-corrected. For a room-correction box that is the worst failure mode -
    you keep listening, uncorrected, with no way to know.
    The Teensy now emits a machine-readable "FIRERR <ch> <code> <file>" beside
    each human-readable ERROR line (codes: nosd, missing, poolfull, toobig,
    nomem). The ESP records them per output, clears them whenever a load is
    reque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
    [api_fir.cpp, config.cpp, fir_filters.ino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]
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2026-08-17 Fix Teensy CI: build the native tests on Linux
    The teensy CI job has been failing on every commit, including before this
    session's work. Both causes are macOS-only blind spots - the host build has
    presumably never worked anywhere else.
    CMSIS-DSP's arm_math_types.h selects a compiler branch: _MSC_VER and
    __APPLE_CC__ define __ALIGNED/__STATIC_FORCEINLINE/__STATIC_INLINE/__WEAK
    inline, and everything else falls through to #include "cmsis_compiler.h" - a
    CMSIS-Core header the vendored copy in host_libs does not include. So the
    native environment compiles on a Mac and dies on Linux with "cmsis_compiler.h:
    No such file". Define __GNUC_PYTHON__, CMSIS's own host-build flag, whose
    branch is identi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
2026-08-17 Align the Analyzer mic/source only within the output's passband
    The auto-EQ offset was aligned over a fixed 200-5000 Hz window regardless
    of which output was soloed. A subwoofer reproduces nothing there, so the
    mic read noise floor and the offset was computed from garbage - the whole
    delta curve inherited it, yielding huge boosts or cuts.
    Derive the alignment band from the scoped output's crossover (passband,
    trimmed a half octave in from each corner) and gate it by the mic noise
    floor, so the offset comes only from bands with real signal. Re-center the
    target curve over the same window so it can't fight the alignment. Full-
    range and input scopes keep the 200-5000 Hz midrange.
    Also drop t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
2026-08-17 Tap the RTA post-crossover for a soloed output
    The RTA "source" trace was always the full-range pre-DSP L+R mix, even
    when the analyzer soloed one output. A soloed subwoofer therefore showed
    full-range source energy against a mic that only hears the passband, so
    the mic/source comparison was fundamentally mismatched (the WebUI now
    works around it by aligning within the passband; this fixes it at source).
    updateRtaSource() switches the FFT input to the soloed output's post-
    crossover, pre-PEQ signal, so the source trace is band-limited exactly
    like the driver - matching the input scope's "pre-EQ source, measure with
    EQ bypassed" semantics. The reroute happens only when the solo target
    actual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
    [fir_filters.ino]
2026-08-17 Fix config restore endpoint
    [web_server.cpp]
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2026-08-21 Another attempt at web server stability
    [health.cpp]
2026-08-21 Add SD recorder: record the stereo input, play back saved recordings
    Records the mixed stereo input (pre input-EQ, volume-independent) to
    /recordings on the Teensy's SD card as 16-bit 44.1kHz WAVs, with playback
    through the input chain (aux mixer input 2) so recordings run through the
    active preset like any other source. Only available while a card is present;
    the UI hides the recorder without one.
    Teensy: SdRecorder drains two AudioRecordQueue taps in 512-byte sector
    writes (zero static RAM2 - the ~15KB heap slack at a full FIR pool stays
    intact) and re-patches the WAV header every 5s so a crash costs seconds,
    not the file. SdWavPlayer is a custom AudioStream that reads SD only from
    loop()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
    [api_fir.cpp, button.cpp, fir_filters.ino]
2026-08-22 Fix recordings dying ~2s in: stop probing SD media while a stream is open
    recorderStatusLoop polled sdReady() -> SD.mediaPresent() once per second
    while recording - the one moment the bus is guaranteed busy. SdFat's SDIO
    driver keeps a multi-block write transfer open between the recorder's
    sector writes (m_curState = WRITE_STATE), a CMD13 issued mid-transfer
    can't complete, statusCMD13() returns 0, and SD.mediaPresent() reads zero
    status as "card removed". sdReady() believed it, and one tick later
    "re-mounted" the card - SD.begin() re-initializing the volume under the
    recorder's open file. The next write failed and the recording auto-stopped
    with REC ERR write at ~2 seconds, every time. (The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
    [fir_filters.ino]
2026-08-22 Reserve the FIR arena statically instead of reallocating it per load
    A full pool needs ~206KB in one contiguous heap run, and re-requesting that
    only worked while the heap was pristine: toggling one filter off and on
    freed the block, claimed a smaller one, and the follow-up full-size request
    then failed, dropping the largest filter (FIRERR nomem on a 3072/3072/6144
    set). The arena is now a fixed DMAMEM block sized for the worst case fast
    convolution can need, so every set the pool check accepts fits by
    construction - pass 2 of loadFirFiles can no longer fail and the per-filter
    fallback is gone. Also documents that mallinfo's numbers exclude malloc's
    top chunk, so the linker's "free for mallo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
    [fir_filters.ino]
2026-08-22 Add SD playback level control and a stereo input level meter
    Playback fed the input mix at a hardwired unity gain - the only source
    without a level control - so a hot recording on top of a live input clipped
    the bus with no way to back it off. The aux mixer's player input now has a
    gain: "setPlaybackGain <0..1>" on the wire (its own command; the message
    builder carries five parameters and setInputGains uses all five), a
    "recorder" key on PUT /gains/input and /status (device-wide and persisted
    like the other input gains, defaulting via the existing missing-key path so
    no config migration), and a -40..0dB slider on the Recorder card. The
    Teensy re-applies it inside setInputGains so the probe's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
    [config.cpp, config.h, fir_filters.ino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]
2026-08-22 Fix analyzer crashing the DSP: RTA buffers static, pool charged in partitions
    Opening the analyzer hard-faulted the Teensy (DACCVIOL at 0x0, outputs
    buzzing the last DMA block until the auto-reboot). RtaFFT4096's constructor
    heap-allocates five buffers with unchecked new; the static FIR arena had
    shrunk the RAM2 heap to within ~700 bytes of what boot-time allocations
    need, so the fourth allocation (spectrum, 16KB) quietly returned nullptr at
    static-init - boot ran fine, and the first analyze() stored through null
    (confirmed: vstr through r7=0 in stage_rfft_f32; the at-rest heap showed
    exactly 16,384 bytes sbrk never handed out).
    Two structural fixes:
    - The RTA's buffers are now fixed DMAMEM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
    [api_fir.cpp, fir_filters.ino, teensy_protocol.h]
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2026-08-22 Apply the teal brand to the WebUI: nav wordmark, icons, manifest; blue -> teal
    Nav brand is the small-cut wordmark SVG inlined as currentColor (no extra
    request on the device's scarce TLS sockets). Manifest/theme colours fixed
    to the shipped #10141a/#161b22; icons split into any + maskable PNGs; new
    favicon drawn for 16 px. The interactive blue moves into the brand's teal
    family: Teal 500 #17808D for fills (white text 4.7:1), Teal 300 #45AEBC
    for active text, links and chart traces (Teal 500 as text on dark is only
    3.7:1, so the split is load-bearing). Amber now only ever means in-effect.
2026-08-22 Analyzer RTA: bar and peak-hold layers over the averaged traces
    The spectrum chart was two lines. Each trace now draws three layers: bars
    for the fast level (0.18s power EMA of the raw frames), a peak tick that
    holds 800ms then falls at 15 dB/s, and the existing time-averaged line on
    top. The average is unchanged and remains the only thing the deviation
    chart and the EQ fitter read - peaks and bars are display only.
    Source and mic bars share a baseline, so the shorter always sits inside
    the taller. The overlap is painted green and the single-colour cap above
    it is exactly mic - source, the same quantity the delta chart plots
    underneath. The mic moves from the semantic "live" green to amber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
2026-08-24 Stop request bursts wedging the device, and let a restart recover
    Three changes, all from telemetry rather than guesswork - a /status poller
    running 2026-08-20..24 caught the failure end to end.
    HTTPS max_open_sockets 3 -> 2. At ~40KB per TLS connection, 3 budgets
    ~120KB, and polling showed steady-state freeInternal is 103,692-120,580 and
    drifts DOWN with uptime, not the 132,444 the 2026-08-15 figure assumed. So 3
    permitted an allocation larger than the entire heap. On 2026-08-24 one cold
    phone page load (html 11.7KB + js 89KB + favicon + manifest + icons, enough
    separate requests for a browser's full parallel set, while a desktop HTTP tab
    held a websocket) collapsed freeInternal from 110,3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
    [health.cpp, web_server.cpp]
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2026-08-24 Enable the 8MB PSRAM; restore LRU eviction on the HTTPS listener
    board_build.arduino.memory_type = qio_opi + -DBOARD_HAS_PSRAM on the esp32s3
    env. Verified live: psramSize 8,388,607, and GET /status now reports
    psramFree/psramSize so this is checkable rather than assumed.
    WHAT IT ACTUALLY BOUGHT, and what it did not. The prebuilt Arduino SDK sets
    CONFIG_MBEDTLS_INTERNAL_MEM_ALLOC=y, so mbedTLS allocates from internal RAM
    regardless of PSRAM - the 16KB record buffers do NOT relocate, and psramFree
    barely moves across a TLS burst (8,370,051 -> 8,367,723). The earlier
    assumption that ALWAYSINTERNAL=4096 would move them was wrong.
    What does relocate is WiFi/lwIP (CONFIG_SPIRAM_TRY_ALLOCATE_WIF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
    [health.cpp, web_server.cpp]
2026-08-24 Queue API requests onto one connection so they stop losing the socket race
    Lance reported frequent failed API requests whenever the live-updates
    websocket was connected. Cause: the HTTPS listener affords 2 TLS sockets at
    ~50KB of internal heap each and the websocket permanently holds one - it
    carries 20 state-change broadcast types (activePresetChanged, volumeChanged,
    firLoadError, recorderState, ...) so it cannot be opened lazily without the UI
    going stale when the IR remote or front button changes something. That leaves
    exactly one socket for REST.
    Nothing respected that. There is no Promise.all in the app, but a view mount
    has five or six components each loading independently in the same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
2026-08-25 Add an iPhone 17 Pro mic profile: the acoustic path only, not the browser's
    Faber Acoustical's anechoic measurement of the 17 Pro, digitised from the
    pressure-corrected trace. Flat within ~1.5 dB from 100Hz to 5kHz, so it
    lands almost entirely on the low end - +13 dB at 20Hz, +10 at 25.
    That flat region is also the 200Hz-5kHz window medianOffset aligns on, so
    the profile barely moves the alignment and mostly just restores bass the
    mic never captured. Without it, auto-EQ reads the roll-off as a room
    deficit and spends its boost budget filling it in.
    Deliberately the acoustic path alone: Faber measured through iOS
    measurement mode, which disables the voice-processing high-pass, and
    whether S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
2026-08-26 Probe the LCD over Wire directly: isConnected() faults before begin()
    The LCD retry added in 10e8d45 boot-looped the S3 on every start, so the
    device never reached WiFi:
    Guru Meditation Error: Core 1 panic'ed (LoadProhibited)
    EXCVADDR: 0x00000040 A2: 0x00000000
    setupScreen() screen.cpp:51 -> LiquidCrystal_PCF8574::isConnected()
    LiquidCrystal_PCF8574 assigns its _i2cPort only inside begin(); the
    constructor's init() never touches it, so the pointer is null until the
    one-shot HD44780 init has run. isConnected() dereferences it with no
    guard. Probing before init - the entire point of the retry - therefore
    faults every time, unconditionally.
    initI2C() running first is not enough: Wire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
    [screen.cpp]
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2026-08-30 Extract the audio hold and FIR file loading from the sketch
    The hold state machine (boot hold, nested sync holds, FIR-load hold, and
    the idle fail-safe) was scattered across three parts of fir_filters.ino;
    it is now AudioHold.h - hardware-free, with the whole machine on one
    screen and a native test suite covering the nesting, the lost-release
    fail-safe, and millis wraparound. The three-pass FIR load (size/carve/
    fill) and its static arena move verbatim to FirFiles.cpp. SketchState.h
    is the sketch's exported surface: the state structs plus the objects and
    services the new translation unit shares. Also retires the .ino
    prototype-generator workaround - OutputState now comes from a header
    above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
    [fir_filters.ino]
2026-08-30 Extract the telemetry streamers and the delay probe from the sketch
    The RTA/GRM/VU frame senders move to TelemetryStreams.cpp, with the
    keepalive/interval pattern they each hand-rolled (enabled flag, two
    timestamps, timeout and pacing checks) collapsed into KeepaliveStream.h -
    hardware-free, with a native test covering the edge detection, expiry
    boundaries, and millis wraparound. The delay probe (cleanup, start,
    chirp-schedule tracking) moves verbatim to DelayProbe.cpp behind a small
    accessor API, so the probe's solo state is no longer sketch globals.
    Graph wiring stays in the sketch: updateRtaSource keeps the FFT tap, and
    the modules reach the graph objects through SketchState.h's externs.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
    [fir_filters.ino]
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2026-08-30 Add the FIR upload/delete path and the measurement sweep command (slice A)
    Browser to SD in two phases: the HTTP body stages chunk-by-chunk into a
    LittleFS temp file (the wire protocol needs the whole file's CRC32 before
    firPutBegin, and staging through flash keeps that compatible with never
    holding the file in RAM), then drains to the Teensy as base64 lines under
    the 80-byte message cap with a 16-line ACK window, one blocking op at a
    time. The Teensy verifies size+CRC and renames a temp file into place -
    failure always leaves the SD untouched. DELETE refuses names any preset
    still references. startSweepProbe parameterizes the probe machinery
    (runtime f0/f1/length/fade, ascending passes, par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
    [api_fir.cpp, teensy_comm.cpp, teensy_comm.h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]
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2026-08-30 Fix FIR uploads failing on every realistic kernel
    First hardware session for the auto-FIR path: POST /fir/upload failed
    100% above ~1,500 taps (0/3 at 1536/2048/3072, and a four-output Apply
    failed 4/4). Since planTapBudget allocates 256-8192 taps per output, the
    wizard's Apply could never have completed. Native tests never caught it -
    the fake stream has neither an SD card nor a UART buffer.
    Root cause: sdReady() probed SD.mediaPresent() while the upload held its
    temp file open. The guard only covered sdRecorder/sdPlayer, so a FIR
    upload wasn't a "stream"; the probe reads as card-removed mid-transfer
    and the remount orphans the open handle, so the next write comes back
    short. This is exact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
    [fir_filters.ino, teensy_comm.cpp, teensy_protocol.h]
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2026-09-12 Draw and pad for the bell the Teensy actually runs
    The WebUI curve, the auto-EQ fitter and the headroom pad all evaluated the
    analog bell prototype, while the Teensy's SVF realises the RBJ cookbook
    biquad - its bilinear transform. Identical below ~3 kHz, but the digital
    bell narrows toward Nyquist and is exactly flat at fs/2: 1.2 dB apart at
    10 kHz Q4, 2.6 dB at 15 kHz Q10, and the app drew +5.8 dB at 22 kHz for a
    20 kHz Q1 bell where the device does 0 dB.
    peakingBellDb and calculateBellFilter now evaluate the prototype at the
    warped ratio tan(pi f/fs)/tan(pi fc/fs) - the exact digital response -
    with the device's parameter clamps applied, so they describe the band that
    runs. The device rat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
    [fir_filters.ino]
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2026-09-13 Report the WiFi link on /status so a bad radio is visible
    The UI stopped loading at vybes.local while every number the device
    reported read clean: 73 minutes of uptime, 121KB free internal, 86KB
    largest block, no restart streak, not degraded. The page was served
    correctly too - byte-identical gzip, right headers - it just crawled at
    ~4.5KB/s over HTTP and reset partway through over HTTPS. The cause was
    25% packet loss on the radio, pinning throughput at roughly one TCP
    segment per round trip. Nothing in the health block said a word about
    the link, so finding it needed a laptop pinging the device against
    another host on the same AP.
    rssi alone would have been nearly as useless: it swings sev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
    [health.cpp]
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2026-09-20 Sweep each output at its own trim, not at full probe level
    While a probe runs, outputTargetGain() replaced the entire
    gain/mute/volume product with the fixed probe level. Overriding master
    volume and mute is deliberate - neither may silence a measurement - but
    the per-output trim was going with them, and that one is not noise, it
    is the level the output is meant to run at.
    A sub trimmed to -5.8 dB was swept at -12.0 dBFS instead of -17.8:
    nearly 6 dB hotter than anything it sees in use, held as a sustained
    sine for the 0.71 s the log sweep spends below 105 Hz, twice per
    session. With no high-pass on that output the sweep starts at 20 Hz,
    below where most boxes load at all, and it distorts a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
    [fir_filters.ino]
